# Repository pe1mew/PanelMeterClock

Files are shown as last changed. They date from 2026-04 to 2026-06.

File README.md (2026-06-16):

# PanelMeterClock

A wall clock that displays the current local time on three Siemens 1604P moving-coil panel meters, driven by an ESP32-S3. Hours, minutes, and seconds each have a dedicated meter whose needle deflects proportionally to the time value. Time is obtained via NTP over WiFi, with optional GNSS disciplining for higher accuracy. The device is configured entirely through an embedded web GUI.

## Features

- Three-meter display: hours (0–24), minutes (0–60), seconds (0–60)
- NTP synchronisation over WiFi (`pool.ntp.org` default, configurable)
- Optional GNSS receiver for hardware 1PPS disciplining and precise UTC
- Automatic Daylight Saving Time from GNSS coordinates or IP geolocation
- Embedded web GUI: meter calibration, WiFi config, GNSS config, status, firmware update
- Firmware Over The Air (FOTA) with asymmetric-key signature verification
- mDNS registration (`panelclock.local`) for zero-configuration browser access
- WiFi AP fallback (`PanelClock-XXYY`) when no network credentials are stored
- FreeRTOS firmware on ESP-IDF 5.x / Arduino framework

## Hardware

| Component | Details |
|---|---|
| Microcontroller | WEMOS LOLIN S3 (ESP32-S3-WROOM-1, dual-core 240 MHz, 16 MB flash, 8 MB PSRAM) |
| Panel meters | 3 × Siemens 1604P, 1 V FSD, modified to 3 V FSD by series resistor substitution |
| PWM filter | RC low-pass filter per channel: R = 1 kΩ, C = 4.7 µF, f_c ≈ 34 Hz (PWM 156.25 kHz) |
| Series resistor | 2.0 kΩ ±1 % metal film per meter (measured: I_FSD = 1 mA, R_coil = 82.2 Ω) |
| GNSS receiver | Optional; Quectel L76-M33 (GPS/GLONASS/Galileo/BeiDou, 3.3 V, NMEA 0183, 1PPS, U.FL) |
| GNSS antenna | SMA female chassis connector (J1) via U.FL-to-SMA pigtail; external active or passive antenna |
| Power supply | 5 V via USB-C (LOLIN S3 on-board regulator) |

## Repository Structure

```
PanelMeterClock/
│
├── Design/                              ← Project design documents
│   ├── functionalRequirementsSpecification.md   ← PMC-FRS-001: what the system shall do
│   ├── softwareTechnicalDesign.md               ← PMC-STD-001: firmware architecture
│   ├── hardwareTechnicalDesign.md               ← PMC-HTD-001: circuit design and BOM
│   ├── signatureConciderations.md               ← FOTA signature scheme analysis
│   └── notes.md                                 ← Design trade-off notes
│
├── Documentation/                       ← Component datasheets and reference material
│   ├── esp32-s3-wroom-1_wroom-1u_datasheet_en.pdf
│   ├── esp32-s3_technical_reference_manual_en.pdf
│   ├── dim_s3_v1.0.0.pdf
│   └── sch_s3_v1.0.0.pdf
│
├── Hardware/                            ← Hardware design files
│   └── Scale/                           ← Panel meter scale face designs
│
├── Research/                            ← Standalone PlatformIO validation projects
│   ├── PWMDriver/                       ← PWM driver library (production-ready)
│   │   ├── platformio.ini
│   │   └── src/
│   │       ├── main.cpp
│   │       ├── pwm_driver.h
│   │       └── pwm_driver.cpp
│   ├── PWMTest/                         ← PWM frequency and RC filter verification
│   │   ├── platformio.ini
│   │   └── src/
│   │       └── main.cpp
│   ├── PWMDriver.md                     ← PWM driver design and API documentation
│   └── PWMTest.md                       ← RC filter and frequency verification plan
│
├── README.md
├── LICENSE
├── license.md
├── changelog.md
├── contributing.md
└── code_of_conduct.md
```

## Getting Started

### Prerequisites

- [Visual Studio Code](https://code.visualstudio.com/) with the [PlatformIO IDE extension](https://platformio.org/install/ide?install=vscode)
- Git

### Build and Flash (Research Projects)

The main firmware application is not yet implemented. The `Research/PWMDriver` project validates the PWM driver and RC filter circuit.

1. Clone the repository:
   ```sh
   git clone https://github.com/pe1mew/PanelMeterClock.git
   cd PanelMeterClock
   ```
2. Open `Research/PWMDriver/` in VS Code (PlatformIO detects `platformio.ini` automatically).
3. Connect the LOLIN S3 board via USB-C.
4. Click **Upload** in the PlatformIO toolbar, or run:
   ```sh
   pio run -t upload
   ```
5. Open the **Serial Monitor** at 115200 baud to view PWM and voltage readouts.

### Configuration

The main application is configured through the embedded web GUI at `http://panelclock.local/` once the device is connected to WiFi. On first boot, connect to the fallback AP (`PanelClock-XXYY`) and open `http://192.168.4.1/wifi` to enter WiFi credentials.

## Documentation

| Document | Description |
|---|---|
| [Functional Requirements Specification](Design/functionalRequirementsSpecification.md) | What the system shall do — all functional and non-functional requirements |
| [Software Technical Design](Design/softwareTechnicalDesign.md) | Firmware architecture, FreeRTOS tasks, module design, library choices |
| [Hardware Technical Design](Design/hardwareTechnicalDesign.md) | Circuit design, component values, GPIO assignment, BOM |
| [FOTA Signature Considerations](Design/signatureConciderations.md) | Detached signature scheme analysis and alternatives |
| [PWM Driver Design](Research/PWMDriver.md) | PWM driver API and glitch-free duty update design |
| [PWM Test Plan](Research/PWMTest.md) | RC filter and PWM frequency verification (original 20–80 kHz bench test) |

## License

See [license.md](license.md) for full details.

**Software** (firmware and all code): Source-available, non-commercial. Free to use and modify for personal and non-commercial purposes; redistribution and commercial use are not permitted.

**Hardware design, documentation, and images**: Licensed under the Creative Commons Attribution-NonCommercial-NoDerivatives 4.0 International License.



## Disclaimer

This project is distributed in the hope that it will be useful, but WITHOUT ANY WARRANTY; without even the implied warranty of MERCHANTABILITY or FITNESS FOR A PARTICULAR PURPOSE.

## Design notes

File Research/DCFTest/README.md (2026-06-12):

# DCFTest — DCF77 decoder proof of concept

Proof of concept for the PanelMeterClock DCF77 time source: receive the
demodulated 77.5 kHz time-code signal, decode and validate the one-minute
frame, and report civil CET/CEST time plus derived UTC over the serial
console.

An **ESP-IDF** project (no Arduino layer) with **two interchangeable
decoder components**, both RTOS-aware (dedicated FreeRTOS task, core 0,
priority 7 per PMC-STD-001 §4) with the same callback-driven shape:

* `components/dcf77` — **simple edge-timing decoder**, the PMC-STD-001
  §5.10 baseline. Edge interrupt → pulse-width windows → frame validation →
  consecutive-frame confirmation. Original code, no license constraints.
* `components/dcf77p` — **phase-locked exhaustive decoder**, a C port of
  Udo Klein's blinkenlight decoder (www.blinkenlight.net). 1 kHz sampling →
  100-bin phase convolution → per-second tick classification → 60-bin
  sync-mark scoring → per-field maximum-likelihood (Hamming) binning with
  prediction-driven bin rings. Decodes through noise where individual
  pulses are unreadable. **GPL-3.0** (see below).

`src/main.c` is only the PoC harness: it wires the selected decoder's
callbacks to console printing and stands in for `tick_task`'s epoch
bookkeeping.

```
DCFTest/
├── platformio.ini            framework = espidf, board = lolin_s3
├── CMakeLists.txt            standard IDF project stub
├── sdkconfig.defaults        FREERTOS_HZ=1000, 16 MB flash
├── components/
│   ├── dcf77/                ← edge-timing decoder component
│   │   ├── CMakeLists.txt
│   │   ├── include/dcf77.h
│   │   └── dcf77.c
│   └── dcf77p/               ← phase-locked exhaustive decoder component
│       ├── CMakeLists.txt
│       ├── LICENSE           GPL-3.0 (full text)
│       ├── include/dcf77p.h
│       └── dcf77p.c
└── src/
    ├── CMakeLists.txt        (PRIV_REQUIRES dcf77 dcf77p driver)
    └── main.c                PoC harness: app_main(), printing, LED
```

## Choosing the decoder

`src/main.c`, first line after the header comment:

```c
#define USE_PHASE_DECODER 1   // 1 = dcf77p (Klein port), 0 = dcf77 (edge timing)
```

**License consequence:** `dcf77p` is a derivative of GPL-3.0 code, with the
full text in `components/dcf77p/LICENSE`. Any firmware image that links
`dcf77p` must be distributed under GPL-3.0 terms. The `dcf77` component
carries no such obligation — with `USE_PHASE_DECODER 0` the component is
still compiled but not linked into the image. This was an accepted
trade-off for this research (FDS/TDS deliberately unchanged; the STD still
specifies the simple decoder for the firmware).

Port deviations from the reference sketch
(`Documentation/src/blinkenLightDC77DecoderAll.c`) are documented in
`dcf77p.c`: the year-decoder bit-56 weight bug is fixed, the unused
200-line signal predictor is replaced by its one-line leap-second closed
form, and the AVR busy-wait output is replaced by task-context callbacks.

## Hardware

WEMOS LOLIN S3 dev board + DCF77 receiver module (CME6005-based, see
`Documentation/dcf77.md`). Pinning per PMC-HTD-001 §3/§7:

| Module pin | ESP32-S3 GPIO | Direction | Notes |
|---|---|---|---|
| T (time-code out) | 11 | Input | Internal pull-up enabled (open-collector output, IC-HW-005) |
| P1 (PON / power down) | 12 | Output | **Low = receiver on** (IC-HW-006) |
| V | 3V3 | — | ≈ 1–2 mA |
| G | GND | — | |
| DCF status LED (optional) | 5 | Output | Blinks ~1 Hz while acquiring, steady when valid (PMC-GUI-001) |

Site the ferrite antenna away from the ESP32, USB supply and other switching
noise, broadside toward Frankfurt (PMC-HTD-001 §7.4). Reception is usually
poor right next to a PC/monitor — a metre of separation helps a lot.

## Build and monitor

```
pio run -t upload
pio device monitor
```

115200 baud. Output goes to the default ESP-IDF console = **UART0 / the
CH340 USB port**; the board's native-USB port is unused.

Notes:

* The first build downloads the ESP-IDF framework and toolchain packages
  (large, several minutes); subsequent builds are normal.
* `sdkconfig.defaults` pins `CONFIG_FREERTOS_HZ=1000` (IDF defaults to
  100 Hz) so the decoder's `pdMS_TO_TICKS()`-paced edge flush and watchdog
  keep millisecond granularity. The generated `sdkconfig.esp32s3` is
  git-ignored; delete it to regenerate from the defaults.

## What the serial output looks like

```
DCF77 decoder proof of concept — PanelMeterClock Research/DCFTest
...
[bit ]  ? = 1  (197 ms)  waiting for minute mark
[dcf ] minute mark (1986 ms gap)
[bit ]  0 = 0  (103 ms)  M  start of minute (always 0)
[bit ]  1 = 0  (104 ms)  civil warning / weather
...
[bit ] 58 = 1  (195 ms)  P3 date parity
[dcf ] minute mark (1992 ms gap)
[frame] 0 00111010011010 0 0 1 0 0 1 10101100 0010100 010010 101 01100 011001001
[frame] OK: Fri 2026-06-12 14:35:00 CEST = 12:35 UTC
[frame] awaiting confirmation by the next frame (FR-DCF-007)
... (one more minute of bits) ...
[dcf ] minute mark (1989 ms gap)
[frame] 0 01001011010010 0 0 1 0 0 1 01101100 0010100 010010 101 01100 011001001
[frame] OK: Fri 2026-06-12 14:36:00 CEST = 12:36 UTC
==========================================================
[time] CONFIRMED by two consecutive frames (FR-DCF-007)
==========================================================
[time] 2026-06-12 14:36:00 CEST (UTC 12:36:00)
[time] 2026-06-12 14:36:01 CEST (UTC 12:36:01)
...
[stat] LOCKED | second 23 | edges 412 (3 glitches) | bits 142 ok / 1 bad | frames 2 ok / 0 bad | confirmed 1
```

A first confirmed time takes 2–5 minutes with decent reception: partial
first minute → one full frame → confirmation by the next frame.

With the phase-locked decoder (`USE_PHASE_DECODER 1`) the output instead
shows the acquisition stages and per-minute tick classifications:

```
Decoder: dcf77p — phase-locked exhaustive (Udo Klein port, GPL-3.0)
...
==== state: OFF -> ACQUIRING_PHASE ====
[stat] ACQUIRING_PHASE | sec 0 | ticks S:0 ?:0 0:0 1:0 | phase 64-58 | ...
==== state: ACQUIRING_PHASE -> ACQUIRING_SECOND ====
[tick] 0100110100101S01101011000010100010010101011000110010010S010  (no second lock)
==== state: ACQUIRING_SECOND -> DECODING ====
[dec ] --:--:23  date 20----    (fields locking)
[dec ] --:36:24  date 2026-06-12  (fields locking)
[min ] 00011101001101000101101011000010100010010101011000110010010
==== state: DECODING -> TIME_VALID ====
[time] full date/time determined by exhaustive decoding
[time] 2026-06-12 Fri 14:36:31 CEST (UTC 12:36:31)
[time] 2026-06-12 Fri 14:36:32 CEST (UTC 12:36:32)
```

With good signal the phase lock arrives within ~1 minute and the full time
typically within 3–6 minutes; with poor signal the exhaustive decoder keeps
integrating and can take tens of minutes — but it converges at noise levels
where the edge-timing decoder never produces a clean frame at all.

## How it works — dcf77 (edge timing)

```
GPIO 11 CHANGE ISR ──(timestamped edges)──▶ FreeRTOS queue ──▶ dcf77 task
                                                              (core 0, prio 7,
                                                               PMC-STD-001 §4)
```

* **Glitch filter** — two edges closer together than 20 ms annihilate, so RF
  spikes never reach the decoder. Acceptance of a real edge is delayed by at
  most ~45 ms; events carry the original edge timestamp.
* **Bit classification** — mark width 40–130 ms → `0`, 140–260 ms → `1`,
  anything else poisons the frame and is reported (`PULSE_REJECT`).
* **Second/minute sync** — leading-edge-to-leading-edge period 800–1200 ms →
  next second; 1700–2300 ms → missing 59th mark = minute boundary. Other
  periods drop bit alignment (`RESYNC`).
* **Frame validation (FR-DCF-006)** — 59 bits, bit 0 = 0, bit 20 = 1,
  Z1 ≠ Z2, even parity P1/P2/P3, BCD digit validity, field ranges,
  day-in-month, and weekday cross-checked against the date.
* **Confirmation (FR-DCF-007)** — a decoded time is only reported as
  `TIME_CONFIRMED` once two consecutive frames are exactly one minute apart.
* **UTC (FR-DCF-009)** — broadcast time is civil CET/CEST; the module derives
  the UTC epoch using the Z1/Z2 zone bits (CET = UTC+1, CEST = UTC+2).
* **Ticks (FR-DCF-012)** — every accepted mark leading edge fires a tick
  callback; in the firmware this feeds `tick_task` as the Priority-2 tick
  source.

## How it works — dcf77p (phase-locked exhaustive)

```
1 kHz esp_timer cb ──(10 ms majority bits)──▶ FreeRTOS queue ──▶ dcf77p task
(sampling only)                                                 (core 0, prio 7)
```

* **Phase lock** — each 10 ms slot feeds a saturating up/down counter in
  one of 100 phase bins (cap 300 ≈ 5 min of integration). A sliding
  convolution with the expected pulse shape (2× weight first 100 ms, 1×
  second 100 ms) finds the second boundary; the same kernel 200 ms out of
  phase estimates the noise floor. No edges are ever measured.
* **Tick classification** — the 220 ms window after each boundary is split
  into two 110 ms halves; their majorities yield sync-mark / 0 / 1 /
  undefined per second.
* **Second lock** — a 60-bin scoring scheme (+6 for a sync mark, ±1/−2
  cross-evidence from 0/1 bits, exploiting "bit 0 = 0, bit 20 = 1") finds
  which second of the minute we are in.
* **Exhaustive field decoding** — every minute, each calendar field scores
  *all* its candidate values (60 minutes, 24 hours, 31 days, …) by Hamming
  distance against the received bits (parity included for minute/hour);
  evidence accumulates per candidate in rings that the predicted time keeps
  rotating in lock-step (timezone jumps and month lengths handled by the
  prediction). The best candidate wins once it leads the runner-up by ≥ 2 —
  effectively a maximum-likelihood decoder integrating over minutes.
* **Output** — at every predicted second boundary the controller advances
  the reconstructed time and publishes it (`DCF77P_EVT_SECOND` + tick
  callback, FR-DCF-012); `valid` is set once all fields are determined and
  mutually plausible, and the UTC epoch is derived from the zone bits
  (FR-DCF-009). Trust is structural here: a field value only emerges after
  consistent evidence across minutes, which subsumes the two-frame
  confirmation idea of FR-DCF-007.

## Polarity (FR-DCF-004)

The decoder expects the carrier-reduction mark as a **HIGH** pulse by
default. If your module idles high and pulls low during the mark, the PoC
will print rejected marks of ~800/900 ms and a hint; set

```c
cfg.signal_inverted = true;
```

in `app_main()`.

## Reusing the component in the firmware

* Copy `components/dcf77/` into the firmware's `components/` directory and
  add `dcf77` to the consumer's `PRIV_REQUIRES` — done. The component
  depends only on `driver` (GPIO), `esp_timer` and FreeRTOS; the header is
  C++-safe (`extern "C"` guards). Multiple instances are supported (the ISR
  receives the instance pointer).
* The component installs the shared GPIO ISR service with flags 0 and
  tolerates `ESP_ERR_INVALID_STATE` if the firmware installed it already
  (the GNSS 1PPS and encoder inputs will share it). If the firmware installs
  the service with `ESP_INTR_FLAG_IRAM`, replace the `gpio_get_level()` call
  in the ISR with a register read (see note in `dcf77.c`).
* Callbacks run in the decoder task context — keep them short; hand data to
  other tasks via the usual primitives (the firmware will set the shared
  epoch and notify `tick_task` instead of printing).
* `dcf77_stop()` disables the pin interrupt, removes the handler and holds
  PON off, matching the "disabled consumes no resources" requirement
  (FR-DCF-002); the firmware's NVS flag `dcf77_enabled` maps to start/stop.
* Constants meant for `config.h` (PMC-STD-001 §7): `DCF77_SIGNAL_GPIO` 11,
  `DCF77_PON_GPIO` 12, plus the timing windows in `dcf77_config_default()`.

## Known limitations (PoC scope)

* No free-running bridge across reception gaps — the printed clock simply
  stops when marks stop; in the firmware that is `tick_task`'s job
  (FR-TIM-007). Re-confirmation resumes it.
* `signal_lost_ms` is 5 s for fast bench feedback; the firmware uses
  `DCF77_SIGNAL_LOST_TIMEOUT_S` = 300 (FR-DCF-010).
* A leap-second minute (60 marks) is rejected as a 60-bit frame — one bad
  minute, then normal recovery.
* The simple edge-timing decoder needs a reasonably clean signal; for
  marginal sites the phase-locked `dcf77p` component is the implemented
  alternative (`USE_PHASE_DECODER 1`, GPL-3.0).
* `dcf77p` ports the decoder stages of Klein's sketch but not the later
  library's local-clock flywheel or crystal frequency tuning — during deep
  fades the published seconds keep ticking from the phase prediction, but
  long outages degrade the locks rather than free-running on a disciplined
  local oscillator.
* `dcf77p` samples via a 1 kHz `esp_timer` callback (task-dispatched). That
  is jitter-tolerant by design (10 ms bins, minutes of integration), but a
  heavily loaded system could still starve it; the firmware-grade upgrade
  is a GPTimer ISR feeding the same queue.

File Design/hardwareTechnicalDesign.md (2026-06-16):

# Hardware Technical Design
## PanelMeterClock

---

## 1. Document Control

### 1.1 Identification

| Field | Value |
|---|---|
| Document title | Hardware Technical Design — PanelMeterClock |
| Document ID | PMC-HTD-001 |
| Version | 0.2 (draft) |
| Date | 2026-06-15 |
| Author | Remko Welling |
| Status | Draft — under review |

### 1.2 Revision History

| Version | Date | Author | Change Summary |
|---|---|---|---|
| 0.1 | 2026-04-29 | Remko Welling | Initial draft; hardware design content migrated from PMC-FRS-001 and supplemented with circuit analysis |
| 0.2 | 2026-06-15 | Remko Welling | Raised meter PWM to 156.25 kHz and reduced the RC filter capacitor to 4.7 µF (f_c ≈ 33.9 Hz, −73 dB at PWM) to clear the 77.5 kHz DCF77 band; updated §4.2/§4.4/§5/§11; added EMC open issue HW-011 and hardware test HV-11; corrected the §12 table header |

### 1.3 Relationship to Other Documents

| Document | Role |
|---|---|
| PMC-FRS-001 Functional Requirements Specification | Defines *what* the system shall do |
| PMC-STD-001 Software Technical Design | Defines firmware architecture and module design |
| PMC-GUI-001 GUI / User Interface Specification | Defines the physical operator interface (panel, status LEDs, encoder, connectors) |
| This document (PMC-HTD-001) | Defines *how* the hardware is designed and wired |

---

## 2. Target Hardware Platform

### 2.1 Microcontroller Module — ESP32-S3-WROOM-1-N16R8

| Attribute | Value |
|---|---|
| Module | Espressif ESP32-S3-WROOM-1-N16R8 |
| CPU | Xtensa LX7 dual-core, up to 240 MHz |
| Flash | 16 MB quad SPI (N16) |
| PSRAM | 8 MB octal SPI (R8) |
| SRAM | 512 KB |
| WiFi | 802.11b/g/n 2.4 GHz |
| GPIO voltage | 3.3 V (not 5 V-tolerant) |
| USB | Module native USB (USB-CDC / USB-Serial-JTAG) on GPIO 19/20; the project PCB provides USB-C and the debug UART (HW-010) |
| Operating supply | 3.3 V or 5 V via USB |

### 2.2 Available GPIO on the ESP32-S3-WROOM-1

The table below lists all GPIO pins available for application use after reserving the fixed-function pins.

| GPIO | Reserved for | Direction | Notes |
|---|---|---|---|
| 0 | Strapping / Boot | — | Do not use; affects boot mode |
| 3 | Strapping | — | Do not use |
| 19 | USB D− (UART0 / USB-CDC) | — | Debug serial |
| 20 | USB D+ (UART0 / USB-CDC) | — | Debug serial |
| 26–32 | In-package SPI flash (N16) | — | Not accessible |
| 33–37 | In-package octal SPI PSRAM (R8) | — | Not accessible on N16R8 |
| 43 | UART0 TX (CH340) | Output | Debug serial TX |
| 44 | UART0 RX (CH340) | Input | Debug serial RX |
| 45 | Strapping | — | Avoid |
| 46 | Strapping / input-only | Input only | No internal pull |
| All others | Application use | I/O | 3.3 V max |

---

## 3. GPIO Pin Assignment

All application GPIO assignments are listed below. This table is the single authoritative source for pin allocation; firmware constants in `config.h` (PMC-STD-001 §7) shall match these values.

| GPIO | Signal | Direction | Peripheral | Connected to | Requirement |
|---|---|---|---|---|---|
| 4 | LED — RTC status | Output | GPIO | Front-panel status LED (series R) | IC-HW-008, PMC-GUI-001 |
| 5 | LED — DCF status | Output | GPIO | Front-panel status LED (series R) | IC-HW-008, PMC-GUI-001 |
| 6 | LED — NTP status | Output | GPIO | Front-panel status LED (series R) | IC-HW-008, PMC-GUI-001 |
| 7 | LED — GNSS status | Output | GPIO | Front-panel status LED (series R) | IC-HW-008, PMC-GUI-001 |
| 8 | I2C SDA | I/O | I2C | DS1307 RTC (via 3.3 V↔5 V level shifter) | IC-HW-007 |
| 9 | I2C SCL | Output | I2C | DS1307 RTC (via 3.3 V↔5 V level shifter) | IC-HW-007 |
| 10 | GNSS 1PPS | Input | GPIO interrupt | GNSS module 1PPS output | IC-HW-003 |
| 11 | DCF77 time-code | Input | GPIO interrupt | DCF77 receiver time-code output | IC-HW-005 |
| 12 | DCF77 enable (PON) | Output | GPIO | DCF77 receiver enable input | IC-HW-006 |
| 13 | Encoder A | Input | GPIO interrupt | Rotary encoder channel A (pull-up) | IC-HW-009, PMC-GUI-001 |
| 14 | Encoder B | Input | GPIO interrupt | Rotary encoder channel B (pull-up) | IC-HW-009, PMC-GUI-001 |
| 15 | PWM Hours | Output | LEDC_CHANNEL_0 / LEDC_TIMER_0 | RC filter → Hours meter | IC-HW-001 |
| 16 | PWM Minutes | Output | LEDC_CHANNEL_1 / LEDC_TIMER_1 | RC filter → Minutes meter | IC-HW-001 |
| 17 | PWM Seconds | Output | LEDC_CHANNEL_2 / LEDC_TIMER_2 | RC filter → Seconds meter | IC-HW-001 |
| 18 | GNSS UART RX | Input | UART1 | GNSS module TX | IC-HW-004 |
| 19 | USB D− | — | USB-CDC / UART0 | USB connector | Fixed |
| 20 | USB D+ | — | USB-CDC / UART0 | USB connector | Fixed |
| 21 | GNSS UART TX | Output | UART1 | GNSS module RX | IC-HW-004 |
| 43 | Debug TX | Output | UART0 / CH340 | USB-serial chip | Fixed |
| 44 | Debug RX | Input | UART0 / CH340 | USB-serial chip | Fixed |
| 47 | Encoder button | Input | GPIO interrupt | Encoder push button (pull-up) | IC-HW-009, PMC-GUI-001 |

GPIO 10 is configured as input-only with no internal pull resistor (IC-HW-003). GPIO 11 (DCF77 time-code) is an interrupt-capable input with the internal pull-up enabled (IC-HW-005); GPIO 12 (DCF77 enable) is a push-pull output (IC-HW-006). GPIO 8/9 carry the I2C bus to the DS1307 RTC via a 3.3 V↔5 V level shifter (IC-HW-007). GPIO 4–7 drive the four front-panel status LEDs (push-pull, each with a series resistor); GPIO 13/14 are the rotary-encoder A/B channels and GPIO 47 the encoder push button — all inputs with internal pull-ups and firmware debounce (PMC-GUI-001). All PWM outputs are push-pull 3.3 V. GPIO 21 (GNSS TX) may be left unconnected if the GNSS module requires no runtime configuration.

---

## 4. Panel Meter Drive Circuit

### 4.1 Panel Meter — Siemens 1604P

| Parameter | Value |
|---|---|
| Type | Moving-coil (D'Arsonval) DC panel meter |
| Full-scale deflection (FSD) voltage | 1 V (across meter terminals, factory) |
| Original series resistor | Present in factory configuration; limits current to rated FSD |
| Modified full-scale voltage | 3 V (after series resistor substitution — see §4.3) |
| Scale range | 0 – FSD (linear, continuous) |

### 4.2 Circuit Overview

Each of the three meter channels follows the same topology:

```
ESP32-S3 GPIO ──┬── R_filter (1 kΩ) ──┬── R_series ──[ Meter coil ]── GND
                │                     │
               (PWM)               C_filter
                                   (4.7 µF)
                                      │
                                     GND
```

The RC low-pass filter converts the PWM waveform to a quasi-DC voltage. The series resistor limits the current through the meter coil so that the maximum filter output voltage (3 V) causes exactly full-scale deflection.

### 4.3 Series Resistor Modification

The factory series resistor is sized for a 1 V drive source. It must be replaced with a higher value to adapt the meter to the 3 V PWM output.

**Measured values (Siemens 1604P, this build):**

| Parameter | Symbol | Measured value |
|---|---|---|
| Full-scale current | I_FSD | 1.000 mA |
| Full-scale voltage (coil terminals) | V_FSD | 82.2 mV |
| Coil resistance (derived) | R_coil | 82.2 Ω |

**Formula:**

The DC current path is GPIO → R_filter → R_series → coil → GND. R_filter (1 kΩ) is in series at DC and must be included:

```
R_series = V_drive / I_FSD − R_filter − R_coil
```

**Calculation:**

```
R_series = 3.00 V / 1.000 mA − 1 000 Ω − 82.2 Ω
         = 3 000 − 1 000 − 82.2
         = 1 917.8 Ω
```

Nearest E24 standard value: **2.0 kΩ** (next value up, safe — avoids over-deflection).  
With 2.0 kΩ fitted: I = 3.00 V / (1 000 + 2 000 + 82.2) Ω = **0.973 mA = 97.3 % FSD**.  
The 2.7 % shortfall is trimmed by the per-meter `full_scale` NVS calibration value (FR-DSP-011).

**Note:** R_coil varies between individual meters even of the same type. Measure each meter and calculate its series resistor individually. Use a close-tolerance resistor (±1 % metal film) to ensure calibration accuracy is not limited by component tolerance.

**Design point:** The firmware uses a full-scale duty of 232/255, corresponding to:

```
V_out_max = (232 / 255) × 3.3 V = 3.00 V
```

The 3.3 V GPIO maximum is deliberately not used as the full-scale point. This provides a ≈ 0.3 V safety margin and ensures the meter never reaches mechanical end-stop from a firmware glitch. Firmware constants: `PWM_FULL_SCALE_DUTY = 232`, `V_DRIVE_FULL_SCALE = 3.0 V`.

### 4.4 RC Low-Pass Filter Design

One RC filter is fitted per channel. Values and rationale:

| Component | Value | Tolerance | Notes |
|---|---|---|---|
| R_filter | 1 kΩ | ±5 % (±1 % preferred) | Carbon or metal film; rated ≥ 100 mW |
| C_filter | 4.7 µF | ±20 % | Electrolytic, positive terminal toward GPIO (or non-polar film/ceramic) |

**Cutoff frequency:**

```
f_c = 1 / (2π × R × C) = 1 / (2π × 1 000 × 4.7 × 10⁻⁶) ≈ 33.9 Hz
```

**Attenuation at PWM frequency (156.25 kHz):**

```
A = 20 × log₁₀(f_c / f_PWM) = 20 × log₁₀(33.9 / 156 250) = −73 dB
```

At −73 dB the PWM ripple reaching the meter is negligible (< 0.3 mV peak). Residual mechanical damping of the moving-coil meter suppresses any remaining ripple further.

**DC gain:** 0 dB (unity). The filter introduces no attenuation at DC; the output voltage at any steady duty cycle equals `(duty / 255) × 3.3 V` within the accuracy of the resistor and capacitor tolerances.

**Settling time:** The RC time constant τ = R × C = 4.7 ms. Full settling to < 1 % error requires ≈ 5τ = 24 ms. The panel meter's mechanical inertia (settling time > 500 ms) dominates entirely, so the RC settling time is not the limiting factor.

### 4.5 PWM-to-Voltage-to-Deflection Mapping

| Duty (decimal) | V_out | Meter deflection |
|---|---|---|
| 0 | 0.00 V | 0 % (zero) |
| 64 | 0.83 V | 25 % |
| 128 | 1.66 V | 50 % |
| 192 | 2.49 V | 75 % |
| 232 | 3.00 V | 100 % (FSD) |
| 255 | 3.30 V | > FSD — **do not use** |

The firmware clamps duty to [0, 232] at the display layer. Firmware factory defaults: `zero_offset = 0`, `full_scale = 232` (FR-DSP-014).

---

## 5. LEDC PWM Configuration

The ESP32-S3 LEDC peripheral generates all three PWM signals independently.

| Parameter | Value | Notes |
|---|---|---|
| Clock source | APB clock (80 MHz) | Stable; not affected by CPU frequency scaling |
| PWM frequency | 156 250 Hz | Ultrasonic; clears the 77.5 kHz DCF77 band (§7.4, HW-011); above panel meter mechanical response |
| Resolution | 8 bits (256 steps) | Gives 256 duty positions; adequate for meter accuracy |
| Full-scale duty register value | 232 | Corresponds to 3.00 V output |

**Channel and timer assignment:**

| Meter | GPIO | LEDC channel | LEDC timer |
|---|---|---|---|
| Hours | 15 | LEDC_CHANNEL_0 | LEDC_TIMER_0 |
| Minutes | 16 | LEDC_CHANNEL_1 | LEDC_TIMER_1 |
| Seconds | 17 | LEDC_CHANNEL_2 | LEDC_TIMER_2 |

Each meter uses a dedicated timer so that the PWM frequency of one channel can be changed independently without affecting the others (used during development/calibration).

**Frequency validation:** The original RC + PWM bench test (`Research/PWMTest`) validated the filtering approach across 20–80 kHz with a 10 µF capacitor. The operating point was subsequently **raised to 156.25 kHz** to clear the 77.5 kHz DCF77 reception band — the former 80 kHz fundamental sat only 2.5 kHz away (see §7.4 and HW-011) — and the filter capacitor reduced to 4.7 µF to suit (§4.4). Selection criteria: ultrasonic (> 20 kHz); the fundamental and all harmonics clear of 77.5 kHz (harmonics lie above the fundamental, so a fundamental ≥ 100 kHz cannot fall on 77.5 kHz); the filter corner > 70 dB below the PWM frequency; and an exact integer divider from the 80 MHz LEDC clock (80 MHz ÷ 512 = 156.25 kHz — i.e. ÷2 with 8-bit duty resolution; the 8-bit maximum is 312.5 kHz).

---

## 6. GNSS Hardware Interface

### 6.0 Module — Quectel L76-M33

| Parameter | Value |
|---|---|
| Part number | Quectel L76-M33 |
| Constellations | GPS (L1 C/A), GLONASS (L1OF), Galileo (E1B/C), BeiDou (B1I), QZSS (L1 C/A) |
| Supply voltage (VCC) | 3.3 V (2.8 V – 3.6 V) |
| Backup voltage (VBAT) | 3.0 V nominal (maintains RTC and almanac across power cycles) |
| UART default baud rate | 9 600 baud, 8-N-1 |
| UART configurable baud rates | 4 800 / 9 600 / 14 400 / 19 200 / 38 400 / 57 600 / 115 200 via PMTK command |
| NMEA sentences | $GPRMC, $GPGGA, $GPGSV, $GPGSA, $GNRMC, $GNGGA (and others) |
| 1PPS output voltage | 3.3 V logic (active HIGH, configurable pulse width, default 100 ms) |
| Antenna connector | U.FL (IPEX) on-module |
| Acquisition current | ≈ 18 mA (typical) |
| Tracking current | ≈ 15 mA (typical) |
| Standby current | ≈ 1 mA |
| Cold-start TTFF | ≈ 30 s (open sky, no almanac) |
| Hot-start TTFF | ≈ 1 s (valid almanac and ephemeris in VBAT-retained RAM) |
| Tracking sensitivity | −165 dBm |
| Package | LCC, 10.1 × 9.7 × 2.5 mm |
| Reference document | `Documentation/` — Quectel L76-M33 Hardware Design Guide and Product Specification |

### 6.1 Signal Overview

| Signal | L76-M33 pin | ESP32-S3 GPIO | Level | Notes |
|---|---|---|---|---|
| UART RX (ESP ← GNSS) | TXD | 18 | 3.3 V | NMEA sentence output |
| UART TX (ESP → GNSS) | RXD | 21 | 3.3 V | PMTK command input |
| 1PPS (ESP ← GNSS) | 1PPS | 10 | 3.3 V | Rising-edge interrupt; 100 ms pulse (default) |
| Module power | VCC | — | 3.3 V | Supplied from 3.3 V rail |
| Backup power | VBAT | — | 3.0 V | Coin cell or supercapacitor (see §6.6) |

### 6.2 Level Shifting

The L76-M33 operates natively at 3.3 V. All UART and 1PPS signals are directly compatible with ESP32-S3 GPIO logic levels. **No level shifter is required.**

### 6.3 UART Configuration

| Parameter | Value | Configurable |
|---|---|---|
| Peripheral | UART1 | No |
| RX GPIO | 18 | No |
| TX GPIO | 21 | No |
| Baud rate | 9 600 (default) | Yes — NVS key `clock/gnss_baud`; change applied via PMTK set-baud command then firmware reconnect |
| Frame format | 8-N-1 | No |

At 9 600 baud a complete `$GPRMC` sentence (≈ 70 bytes) arrives in ≈ 73 ms, well within the 1-second tick budget. To change the baud rate at runtime the firmware sends `$PMTK251,<baud>*<checksum><CR><LF>` before reopening UART1 at the new rate.

### 6.4 1PPS Signal

The L76-M33 1PPS output is 3.3 V active-HIGH with a default pulse width of 100 ms. GPIO 10 is configured as a rising-edge interrupt with no internal pull resistor. The ISR has a latency budget of < 10 µs (hardware interrupt response on LX7 core). The interrupt is enabled only while `gnss_task` is running (GNSS enabled).

### 6.5 Antenna

The L76-M33 has an on-module **U.FL (IPEX)** antenna connector. A short U.FL-to-SMA pigtail cable (W1, ≈ 100 mm) connects the module to the **SMA female chassis-mount connector (J1)** on the enclosure panel. An external active or passive GNSS antenna with SMA male plug connects to J1.

Active antennas (with built-in LNA) are recommended for enclosures with limited sky view. The L76-M33 supports active antennas directly; no external LNA bias circuit is required.

### 6.6 Backup Power (VBAT)

The VBAT pin maintains the L76-M33 internal RTC and almanac/ephemeris RAM across main-power cycles, enabling hot-start acquisition (≈ 1 s TTFF vs. ≈ 30 s cold start).

| Option | Component | Notes |
|---|---|---|
| Coin cell (recommended) | MS621FE rechargeable LiMnO₂, 3.0 V | Self-contained; no charge circuit needed; ≈ 2–3 year lifetime at VBAT quiescent current |
| Supercapacitor | 0.1 F, 3.3 V | Maintains data for several hours after power-off; no battery management |
| No backup | — | Cold start only (≈ 30 s TTFF); simpler circuit |

Connect VBAT through a Schottky diode (e.g. BAT54, V_f ≈ 0.3 V) from the 3.3 V rail if the coin cell or supercapacitor is omitted, to prevent VBAT floating.

---

## 7. DCF77 Receiver Interface

### 7.0 Module — DCF77 Longwave Receiver

| Parameter | Value |
|---|---|
| Signal | DCF77 longwave time signal, 77.5 kHz |
| Transmitter | Mainflingen, Germany (PTB atomic-clock reference) |
| Coverage | ≈ 2 000 km radius (Central Europe) |
| Antenna | Ferrite rod (supplied with module) |
| Supply voltage | 3.3 V |
| Output | Demodulated time-code; one mark per second (open-collector, requires pull-up) |
| Enable input | Power-on (PON) control line |
| Typical current | ≈ 1–2 mA |

### 7.1 Signal Overview

| Signal | Module pin | ESP32-S3 GPIO | Level | Notes |
|---|---|---|---|---|
| Time-code output | TCO / OUT | 11 | 3.3 V | One mark/second; ≈ 100 ms = 0, ≈ 200 ms = 1; gap at second 59 |
| Enable | PON / EN | 12 | 3.3 V | Powers the receiver on/off |
| Power | VCC | — | 3.3 V | From 3.3 V rail |
| Ground | GND | — | 0 V | Common ground |

### 7.2 Level Shifting

The receiver operates at 3.3 V; its output is directly compatible with ESP32-S3 GPIO logic levels. **No level shifter is required.** The open-collector time-code output uses the ESP32-S3 internal pull-up on GPIO 11 (IC-HW-005).

### 7.3 Time-Code Signal

DCF77 transmits one amplitude-reduced mark per second: ≈ 100 ms for a binary 0 and ≈ 200 ms for a binary 1, with no mark in the 59th second to delimit the minute. GPIO 11 is configured as an edge interrupt; the firmware measures each pulse width to decode the bits and assembles the one-minute frame (PMC-STD-001 §5.10). The leading edge of each mark is an on-time second boundary and is also used as a 1-second tick reference (FR-DCF-012). Signal polarity is configurable in firmware (FR-DCF-004) to accommodate modules with inverted outputs.

### 7.4 Antenna and Siting

The ferrite-rod antenna should be mounted away from switching-noise sources (the ESP32-S3, the USB supply and the panel-meter PWM lines) and oriented broadside toward Frankfurt for best reception. Reception is region-specific (DC-007) and is generally weaker indoors than GNSS; DCF77 is therefore an optional, supplementary time source.

---

## 8. RTC Interface

### 8.0 Device — DS1307Z

| Parameter | Value |
|---|---|
| Part | Maxim DS1307Z (SOIC-8) |
| Type | I2C real-time clock + 56-byte NVRAM |
| I2C address | 0x68 (fixed) |
| Supply voltage | 5 V (4.5 – 5.5 V) |
| Backup | VBAT coin cell, 3 V (CR2032) |
| Timebase | external 32.768 kHz crystal (12.5 pF) |
| Typical current | ≈ 1.5 mA (VCC) / ≈ 300–500 nA (battery, powered off) |
| SQW/OUT | not used in this design |

### 8.1 Signal Overview

| Signal | DS1307 pin | ESP32-S3 GPIO | Level | Notes |
|---|---|---|---|---|
| I2C SDA | SDA | 8 | 3.3 V ↔ 5 V (shifted) | Via level shifter |
| I2C SCL | SCL | 9 | 3.3 V ↔ 5 V (shifted) | Via level shifter |
| Supply | VCC | — | 5 V | From the USB 5 V rail |
| Backup | VBAT | — | 3 V | CR2032 coin cell |
| Crystal | X1 / X2 | — | — | 32.768 kHz, 12.5 pF |

### 8.2 5 V Operation and Level Shifting

The DS1307 requires a 5 V supply, and its logic-high threshold (V_IH ≈ 0.7 × VCC ≈ 3.5 V) is above the ESP32-S3's 3.3 V output. The I2C bus is therefore routed through a **bidirectional MOSFET level shifter** (3.3 V on the ESP32 side, 5 V on the DS1307 side) with pull-ups on each side. The ESP32-S3 is not 5 V tolerant, so the DS1307 I2C lines must not connect to it directly.

*(A 3.3 V RTC such as the DS3231 would remove the level shifter and improve accuracy; the DS1307Z is the selected part — see PMC-STD-001 §5.11.)*

### 8.3 Backup Battery

A CR2032 coin cell on VBAT keeps the DS1307 running while main power is off, so the time of day is retained (FR-RTC-001). The DS1307 clock-halt / oscillator-stopped flag is read at boot to detect a depleted cell or first use (FR-RTC-005).

---

## 9. Serial Debug Interface

| Parameter | Value |
|---|---|
| Interface | UART0, also exposed via CH340 USB-serial chip |
| USB connector | USB-C on the project PCB |
| Baud rate | 115 200 baud, 8-N-1 |
| GPIO (UART0 TX) | 43 |
| GPIO (UART0 RX) | 44 |
| ESP-IDF console | `esp_log` / `ESP_LOGx` on UART0 |

Firmware logging uses the ESP-IDF console (`esp_log`) on UART0, exposed through the on-board USB-UART (HW-010). Alternatively the module's native USB-Serial-JTAG can carry the console over USB-C, which removes the need for a separate USB-UART chip.

---

## 10. Power Supply

| Parameter | Value | Notes |
|---|---|---|
| Input supply | 5 V via USB-C | Stepped down by the on-board 3.3 V regulator |
| 3.3 V rail | On-board LDO regulator | Supplies ESP32-S3 and GPIO outputs |
| GPIO output current per pin | 40 mA maximum | ESP32-S3 absolute maximum |
| Total GPIO current budget | 1 200 mA maximum (sum of all outputs) | Practical limit lower due to LDO rating |
| Panel meter coil current per channel | ≤ I_FSD (≈ 1 mA typical) | Negligible relative to GPIO budget |
| RC filter current per channel | V_out / R_filter ≈ 3 V / 1 kΩ = 3 mA max | Dominates over meter coil current |
| Total current from GPIO pins (3 channels) | ≤ 10 mA | Well within limits |
| GNSS module (L76-M33), acquisition | ≈ 18 mA | Supplied from 3.3 V rail |
| GNSS module (L76-M33), tracking | ≈ 15 mA | Typical steady-state |
| DCF77 receiver module | ≈ 1–2 mA | Supplied from 3.3 V rail; negligible |
| DS1307 RTC | ≈ 1.5 mA | Supplied from the 5 V rail; ≈ µA on the backup battery when powered off |
| Total estimated system current | ≤ 300 mA | ESP32-S3 WiFi active (≈ 240 mA peak) dominates |

The L76-M33 adds ≤ 18 mA to the 3.3 V rail. The on-board 3.3 V LDO regulator shall be rated for at least 500 mA output; total system current remains well within that limit.

---

## 11. Component List (Partial)

This list covers the signal conditioning and display subsystem. Connectors, PCB, and enclosure are out of scope.

| Qty | Reference | Description | Value / Part number |
|-----|---|---|---|
| 1 | U1 | Microcontroller module | Espressif ESP32-S3-WROOM-1-N16R8 (16 MB flash + 8 MB octal PSRAM) |
| 1 | U6 | 3.3 V regulator | LDO, 5 V → 3.3 V, ≥ 500 mA (project PCB; see HW-010) |
| 1 | J2 | USB-C connector | USB 2.0 — power + native USB data (project PCB; see HW-010) |
| 1 | U7 | USB-UART bridge (optional) | CH340 on UART0 for debug, or use the module's native USB-Serial-JTAG (HW-010) |
| 3 | M1–M3 | Panel meter | Siemens 1604P, 1 V FSD, DC |
| 3 | R1–R3 | RC filter resistor | 1 kΩ ±1 %, metal film, 250 mW |
| 3 | C1–C3 | RC filter capacitor | 4.7 µF, 16 V (electrolytic radial, or non-polar film/ceramic) |
| 3 | R4–R6 | Panel meter series resistor | 2.0 kΩ ±1 %, metal film (per §4.3; measured I_FSD = 1 mA, R_coil = 82.2 Ω) |
| 1 | U2 | GNSS receiver module | Quectel L76-M33 (multi-constellation, 3.3 V, NMEA 0183, 1PPS, U.FL) |
| 1 | BT1 | GNSS backup battery | MS621FE rechargeable 3.0 V LiMnO₂ coin cell (or 0.1 F supercapacitor) |
| 1 | W1 | GNSS antenna pigtail | U.FL male to SMA male, ≈ 100 mm |
| 1 | J1 | GNSS antenna connector | SMA female, chassis mount |
| 1 | U3 | DCF77 receiver module | 77.5 kHz longwave receiver with ferrite antenna, 3.3 V, demodulated time-code output |
| 1 | E1 | DCF77 ferrite antenna | Ferrite-rod antenna (supplied with U3) |
| 1 | U4 | Real-time clock | Maxim DS1307Z (I2C, SOIC-8) |
| 1 | Y1 | RTC crystal | 32.768 kHz, 12.5 pF load |
| 1 | BT2 | RTC backup battery | CR2032 coin cell + holder, 3 V |
| 1 | U5 | I2C level shifter | Bidirectional 3.3 V ↔ 5 V, 2-channel (e.g. BSS138-based) |
| 2 | R7,R8 | I2C pull-up resistors | 4.7 kΩ (3.3 V side; 5 V side per shifter module) |
| 4 | D1–D4 | Status LEDs | White, 3 mm — front panel RTC/DCF/NTP/GNSS |
| 4 | R9–R12 | LED series resistors | ≈ 1 kΩ (tune for brightness) |
| 1 | SW1 | Rotary encoder | Incremental quadrature encoder with push button |

---

## 12. Open Hardware Issues

| ID | Item | Status |
|----|---|---|
| HW-001 | GNSS module selection | ✅ Resolved — Quectel L76-M33; 3.3 V, no level shifter required, U.FL antenna connector, default 9 600 baud (see §6) |
| HW-002 | Series resistor values R4–R6 | ✅ Resolved — I_FSD = 1 mA, V_FSD = 82.2 mV, R_coil = 82.2 Ω → R_series = 2.0 kΩ E24 (see §4.3) |
| HW-004 | GNSS antenna connector | ✅ Resolved — SMA female chassis connector |
| HW-005 | DCF77 receiver module selection | ⚠ Open — generic 77.5 kHz module assumed (3.3 V, demodulated time-code output); confirm specific part and ferrite antenna |
| HW-006 | DCF77 GPIO assignment | ✅ Resolved — time-code GPIO 11 (input, pull-up), enable GPIO 12 (output); see §3, §7 |
| HW-007 | RTC selection and interface | ✅ Resolved — DS1307Z on I2C (SDA 8 / SCL 9, addr 0x68); 5 V part, I2C level-shifted to 3.3 V; 32.768 kHz crystal; CR2032 backup (see §8) |
| HW-008 | RTC backup battery life | ⚠ Open — confirm CR2032 lifetime at the DS1307 backup current and specify the holder / replacement access |
| HW-009 | Panel LED and encoder GPIOs | ✅ Resolved — LEDs GPIO 4–7; encoder A/B/button GPIO 13/14/47 (see §3, PMC-GUI-001) |
| HW-010 | Module carrier circuitry | ⚠ Open — the WEMOS LOLIN S3 dev board is no longer the target; the project PCB must provide the support circuitry the dev board supplied: 3.3 V regulation from USB 5 V, the USB-C connector and native-USB wiring, the debug UART (CH340 on UART0, or the module's native USB-Serial-JTAG — which would free GPIO 43/44), supply decoupling, and the antenna provisions. To be specified. |
| HW-011 | DCF77 / PWM coexistence (EMC) | ⚠ Open — the meter PWM and the DCF77 receiver share the enclosure. The PWM fundamental is set to **156.25 kHz** (raised from 80 kHz, which sat only 2.5 kHz from 77.5 kHz) so it and its harmonics stay clear of the DCF77 band (§5). Mitigations: keep the GPIO→R→C filter loop physically small, and site the ferrite antenna away from the PWM traces (§7.4). Confirm by measurement (HV-11) that DCF77 decodes with all three meters sweeping. |

---

## 13. Verification and Test Criteria (Hardware)

Electrical and mechanical checks supporting the functional acceptance criteria of PMC-FRS-001. Firmware-level test cases are in PMC-STD-001 §8.

| ID | Method / setup | Pass criterion | Verifies |
|----|---|---|---|
| HV-01 | Sweep each meter channel duty 0→232; measure V_out at the RC filter node | Output linear with duty (R² ≥ 0.999); ≈ 0 V at 0, ≈ 3.0 V at 232 | FR-DSP-004..006, DC-003..004 |
| HV-02 | At full-scale duty, check needle against the mechanical end-stop | Needle near full scale with margin to the end-stop | FR-DSP-005, FR-DSP-014 |
| HV-03 | Observe ripple at the meter terminals at a held duty | Ripple negligible (< ~1 % FSD); no visible needle jitter | FR-DSP-008, IC-HW-002 |
| HV-04 | Power-off / reset and observe the needles | Needles fall to zero promptly (no sustained drive) | NFR-PWR-001 |
| HV-05 | Check logic levels on the GNSS and DCF77 signal pins | All within 3.3 V logic; no level shifter required | IC-HW-003..006 |
| HV-06 | Verify GNSS antenna path and backup-power hot-start | Fix acquired via the antenna; hot-start after brief power loss | §6.5, §6.6 |
| HV-07 | Verify DCF77 reception with the ferrite antenna sited away from noise | Frames decode reliably at the installation site | FR-DCF-005..007, DC-007 |
| HV-08 | Measure total supply current in the worst case | Within the on-board 3.3 V regulator budget | §10 |
| HV-09 | Verify RTC I2C communication, timekeeping and battery-backup retention | RTC responds at 0x68; keeps time; retains time with main power removed (coin cell fitted) | FR-RTC-001..005, IC-HW-007 |
| HV-10 | Verify each status LED and the rotary encoder | All four LEDs controllable; encoder produces clean quadrature steps and debounced button events | IC-HW-008..009, PMC-GUI-001 |
| HV-11 | With DCF77 receiving, drive all three meters sweeping full scale; compare the DCF77 decode / parity-error rate against meters held static. Probe for PWM emission near 77.5 kHz at the ferrite antenna | No significant rise in DCF77 error rate with meters active; the 156.25 kHz PWM fundamental and its harmonics do not appear in the 77.5 kHz passband | FR-DCF-005..007, DC-004, HW-011 |

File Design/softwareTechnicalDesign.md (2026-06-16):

# Software Technical Design

## PanelMeterClock Firmware

---

## 1. Document Control

### 1.1 Identification

| Field | Value |
|---|---|
| Document title | Software Technical Design — PanelMeterClock Firmware |
| Document ID | PMC-STD-001 |
| Version | 0.3 (draft) |
| Date | 2026-06-15 |
| Author | Remko Welling |
| Status | Draft — under review |

### 1.2 Revision History

| Version | Date | Author | Change Summary |
|---|---|---|---|
| 0.1 | 2026-04-29 | Remko Welling | Initial draft; content migrated from PMC-FRS-001 appendices and supplemented with architecture design |
| 0.2 | 2026-06-09 | Remko Welling | Adopted the Greenhouse-Controller OTA design (new §5.13): dual app banks + paired dual-LittleFS assets, paired atomic commit (FW_DONE + 120 s fallback), 3-fail rollback with healthy-mark, `/api/ota` state machine, OTA-in-progress flag, reboot worker, `coredump` partition. Repartitioned §3.3; added `ota_task` (§4), NVS `system/*` keys (§6), OTA constants (§7), TC-OTA-001 (§8.14), DC-009/DC-010 (§9), IC-SW-004 (§10). Ed25519 firmware signing retained. |
| 0.3 | 2026-06-15 | Remko Welling | Raised meter PWM from 80 kHz to 156.25 kHz to clear the 77.5 kHz DCF77 band; reduced the RC filter capacitor 10 µF → 4.7 µF to match (PMC-HTD-001 §4.4, §5). Updated `PWM_FREQ_HZ` (§7), DC-004 (§9), §5.2; added a DCF77/PWM coexistence step to TC-DCF-001 (§8.7). |

### 1.3 Relationship to the FRS

This document is the companion technical design to **PMC-FRS-001 (Functional Requirements Specification)**. The FRS defines *what* the firmware shall do; this document defines *how* it is structured and implemented. Requirements are identified by their FRS identifiers (e.g., FR-DSP-006).

---

## 2. Target Platform

| Attribute | Value |
|---|---|
| Module | Espressif ESP32-S3-WROOM-1-N16R8 |
| CPU | Xtensa LX7 dual-core, 240 MHz |
| Flash | 16 MB quad SPI (N16) |
| RAM | 512 KB SRAM + 8 MB octal PSRAM (R8) |
| Framework | Espressif ESP-IDF 5.x (mandatory) |
| Build system | PlatformIO |
| RTOS | FreeRTOS (provided by ESP-IDF) |

---

## 3. Build System

### 3.1 `platformio.ini`

```ini
[env:esp32s3]
platform                = espressif32
board                   = esp32-s3-devkitc-1   ; ESP32-S3-WROOM-1 reference; adjust for the project PCB
framework               = espidf
monitor_speed           = 115200
board_build.flash_size  = 16MB
board_build.partitions  = partitions_ota.csv
; N16R8 octal PSRAM is enabled in sdkconfig (CONFIG_SPIRAM, CONFIG_SPIRAM_MODE_OCT).
; No external lib_deps: HTTP server (esp_http_server), WiFi (esp_wifi/esp_netif),
; mDNS (mdns), NVS (nvs_flash) and the UART/GPIO/I2C/LEDC drivers are ESP-IDF components.
```

### 3.2 Library Dependencies

| Library | Source | Purpose | Rationale |
|---|---|---|---|
| `esp_wifi` + `esp_netif` + `esp_event` | Built-in (ESP-IDF) | STA and AP mode (FR-NW-001..009) | Core ESP-IDF networking stack |
| `mdns` | Built-in (ESP-IDF component) | mDNS / DNS-SD registration (FR-NW-010..013) | No external dependency |
| `esp_http_server` | Built-in (ESP-IDF) | Embedded HTTP server and OTA upload (FR-WEB-001..053) | Streams the OTA body straight to `esp_ota_write()` |
| `nvs_flash` | Built-in (ESP-IDF) | NVS key-value storage (FR-DSP-010..012, FR-NW-001) | Native ESP-IDF NVS |
| Custom POSIX TZ parser | In-tree (`src/posix_tz.h`) | DST rule engine (FR-DST-001..006) | POSIX TZ strings are compact, updatable via NVS without firmware rebuild |
| GNSS NMEA parser | In-tree (`src/nmea.h`) | NMEA sentence parsing (FR-GPS-003) | Lightweight; parses $GPRMC/$GNRMC only |
| DCF77 time-code decoder | In-tree (`src/dcf77.h`) | DCF77 frame decode, validation and DST bits (FR-DCF-003..011) | Simple edge-timing decoder; no external library |
| RTC driver (DS1307) | In-tree (`src/ds1307.h`) | Battery-backed RTC over I2C (FR-RTC-001..006) | BCD register read/write at I2C 0x68 via the ESP-IDF I2C driver |
| ESP-IDF peripheral drivers (`driver/`) | Built-in (ESP-IDF) | UART (GNSS), GPIO (1PPS / DCF77 / encoder / LEDs), I2C (RTC), LEDC (PWM) | Native peripheral drivers |
| mbedTLS | Built-in (ESP-IDF) | Ed25519 (Ed25519ph + SHA-256) for FOTA signing (FR-SEC-001..005) | Enable `MBEDTLS_EDDSA_C` in `sdkconfig.defaults`; no extra flash cost |

### 3.3 Partition Table (`partitions_ota.csv`)

Dual app banks paired 1:1 with dual LittleFS asset partitions, plus `otadata` and a `coredump` partition (DC-005, §5.13):

```
# Name,   Type, SubType,  Offset,    Size,     Flags
nvs,      data, nvs,      0x9000,    0x5000,
otadata,  data, ota,      0xe000,    0x2000,
app0,     app,  ota_0,    0x10000,   0x200000,
app1,     app,  ota_1,    0x210000,  0x200000,
lfs0,     data, spiffs,   0x410000,  0x180000,
lfs1,     data, spiffs,   0x590000,  0x180000,
coredump, data, coredump, 0x710000,  0x10000,
```

- **`app0`/`app1`** — the two firmware banks (2 MB each); one active, one the OTA target.
- **`lfs0`/`lfs1`** — LittleFS web-asset partitions paired to the app banks (`app0→lfs0`, `app1→lfs1`); the running image mounts its own, the OTA writer writes the other (§5.13).
- **`coredump`** — crash-dump capture; must be erased on a new unit's first (greenfield) flash, not by OTA (DC-010).

The FOTA public key (FR-SEC-001) is embedded in the firmware binary at build time, not a partition.

---

## 4. FreeRTOS Task Architecture

All application work runs in FreeRTOS tasks created from `app_main()` (the ESP-IDF entry point).

| Task name | Core | Priority | Stack (bytes) | Responsibility |
|---|---|---|---|---|
| `display_task` | APP (1) | 10 | 4096 | Drives the three PWM meters; executes once per 1PPS tick event (FR-DSP-007) |
| `tick_task` | APP (1) | 9 | 2048 | Maintains UTC epoch; synthesises software 1PPS via FreeRTOS timer; arbitrates tick and epoch source; seeds from and writes back the RTC (FR-TIM-001..008, FR-RTC-001..006, FR-BOOT-016) |
| `ntp_task` | PRO (0) | 5 | 4096 | Issues NTP queries; disciplines the epoch (FR-NTP-001..004, FR-BOOT-006) |
| `wifi_task` | PRO (0) | 6 | 4096 | STA connect/reconnect with exponential back-off; AP fallback; mDNS start/stop (FR-NW-001..013) |
| `gnss_task` | PRO (0) | 7 | 4096 | UART read; NMEA parsing; 1PPS interrupt latch (FR-GPS-001..009); only created when GNSS is enabled |
| `dcf77_task` | PRO (0) | 7 | 3072 | DCF77 time-code edge capture, frame decode and validation, per-second tick (FR-DCF-001..012); only created when DCF77 is enabled |
| `http_task` | PRO (0) | 4 | 8192 | Embedded web server; serves the GUI pages and the `/api/ota/*` endpoints; owns the OTA state machine (FR-WEB-001..053, §5.13) |
| `ota_task` | PRO (0) | 5 | 4096 | Background OTA — extracts the buffered asset ZIP to the inactive LittleFS, performs the paired boot-slot commit, schedules the reboot worker (§5.13); only created during an update |
| `ui_task` | APP (1) | 8 | 2048 | Drives the four status LEDs and services the rotary encoder / time-set (PMC-GUI-001) |

**Inter-task communication:**

| Signal | Mechanism | Produced by | Consumed by |
|---|---|---|---|
| 1PPS tick event | `xTaskNotifyGive` | `tick_task` (software) or GNSS ISR (hardware) | `display_task` |
| UTC epoch update | Shared `volatile uint64_t` + `portENTER_CRITICAL` | `tick_task`, `ntp_task`, `gnss_task`, `dcf77_task` | All |
| Tick source selection | Atomic flag (`volatile uint8_t`) | `wifi_task`, `gnss_task`, `ntp_task`, `dcf77_task` | `tick_task` |
| Epoch source selection | Atomic flag (`volatile uint8_t`) | `gnss_task`, `ntp_task`, `dcf77_task` | `tick_task` |
| Config change | FreeRTOS event group | `http_task` | `wifi_task`, `ntp_task`, `gnss_task`, `dcf77_task` |
| OTA in progress | FreeRTOS event-group bit | `http_task`, `ota_task` | `wifi_task`, `tick_task`, status pushes (defer non-essential work, §5.13) |
| OTA state / progress | Mutex-guarded struct | `http_task`, `ota_task` | `http_task` (`GET /api/ota/status`) |

---

## 5. Module Design

### 5.1 Boot State Machine

The firmware progresses through three phases (FR-BOOT-001..017). The table below is the authoritative state-transition design.

| Current state | Event / guard | Next state | Actions on transition |
|---|---|---|---|
| *(start)* | Power-on | `PHASE_1` | Read the RTC and initialise the epoch from it (00:00:00 if the RTC time is invalid); start the 1 Hz software tick in `tick_task` (FR-RTC-002, FR-BOOT-002) |
| `PHASE_1` | Always (immediately) | `PHASE_2` | Create `wifi_task`; begin STA association attempt |
| `PHASE_2` | Always (if GNSS enabled) | `PHASE_3` | Create `gnss_task`; start GNSS UART; enable 1PPS GPIO interrupt |
| `PHASE_2` | Always (if DCF77 enabled) | `PHASE_3` | Create `dcf77_task`; power up receiver; enable time-code GPIO interrupt |
| `PHASE_2` | WiFi association success | `PHASE_2` (NTP attempt) | Issue NTP query from `ntp_task`; start mDNS; set DHCP hostname |
| `PHASE_2` | Valid NTP response | `STEADY` (NTP) | Set epoch from NTP; switch tick source to synthesised 1PPS; log sync event (NFR-MNT-002) |
| `PHASE_2` | WiFi or NTP failure | `PHASE_2` (retry) | Increment retry counter; log; wait 15 s then retry (FR-BOOT-008) |
| `PHASE_3` | GNSS fix valid | `STEADY` (GNSS override) | Override epoch from GNSS; switch tick source to hardware 1PPS; log (NFR-MNT-002) |
| `PHASE_3` | GNSS fix lost (> 5 s) | `PHASE_3` (degraded) | Fall back to NTP synthesised 1PPS; log (FR-BOOT-015) |
| `PHASE_3` | DCF77 valid AND no GNSS AND no NTP | `STEADY` (DCF77) | Set epoch from DCF77 (converted to UTC); drive tick from DCF77 second mark, else synthesised 1PPS; log (FR-BOOT-019) |
| `STEADY` (any) | NTP re-sync interval elapsed | `STEADY` | Issue NTP query; step epoch if error > 1 s, else slew (FR-TIM-006) |
| `STEADY` (any) | GNSS fix re-acquired | `STEADY` (GNSS override) | Re-enable hardware 1PPS; update epoch |
| `STEADY` (any) | Watchdog timeout | `PHASE_1` | Hardware reset; boot from scratch (NFR-REL-001..002) |

On every transition that sets the epoch from an accurate source — NTP, GNSS or DCF77, including the `STEADY` re-sync transitions above — `tick_task` also writes the corrected UTC back to the DS1307 RTC so the battery-backed time stays accurate (FR-RTC-003, §5.11).

### 5.2 Display and PWM Driver

**Duty cycle computation** (FR-DSP-006):

```
duty = zero_offset + round( value / range_max × (full_scale − zero_offset) )
```

Where:
- `value` — current time component (0–24 for hours, 0–60 for minutes/seconds)
- `range_max` — 24 (hours) or 60 (minutes/seconds)
- `zero_offset`, `full_scale` — per-meter calibration values from NVS (8-bit, 0–255)
- Result is clamped to [0, 255] before passing to `pwm_driver_set_duty()`

**PWM driver API** (NFR-PORT-001) — the sole interface between the display logic and LEDC hardware:

```cpp
// Research/PWMDriver/src/pwm_driver.h
void pwm_driver_init(pwm_driver_t *drv, int gpio, ledc_channel_t ch,
                     ledc_timer_t tmr, uint32_t freq_hz, uint8_t duty);
void pwm_driver_set_freq(pwm_driver_t *drv, uint32_t freq_hz);
void pwm_driver_set_duty(pwm_driver_t *drv, uint8_t duty);
```

`display_task` blocks on `ulTaskNotifyTake(pdTRUE, portMAX_DELAY)` and wakes on each 1PPS event. It applies the UTC-to-local conversion, computes duty for each meter, and calls `pwm_driver_set_duty()` three times. Total latency budget: < 10 ms (NFR-PERF-001).

**GPIO and LEDC assignments:**

| Meter | GPIO | LEDC channel | LEDC timer | Range |
|---|---|---|---|---|
| Hours | 15 | `LEDC_CHANNEL_0` | `LEDC_TIMER_0` | 0–24 |
| Minutes | 16 | `LEDC_CHANNEL_1` | `LEDC_TIMER_1` | 0–60 |
| Seconds | 17 | `LEDC_CHANNEL_2` | `LEDC_TIMER_2` | 0–60 |

PWM frequency: 156 250 Hz (80 MHz ÷ 512, exact); resolution: 8-bit; LEDC clock: 80 MHz (DC-004). The frequency clears the 77.5 kHz DCF77 band — see PMC-HTD-001 §5 and §7.4.  
Full-scale duty for 3.0 V output: 232 (= 232/255 × 3.3 V ≈ 3.0 V, FR-DSP-014, DC-003).

### 5.3 Timekeeping Engine

The internal clock is a 64-bit UTC epoch (`uint64_t utc_epoch_s`) plus a sub-second phase accumulator (`int32_t phase_us`).

**Software 1PPS synthesis:** A FreeRTOS timer fires at a nominal 1000 ms period. On each fire, `tick_task` adjusts the timer period by ±1 tick (±1 ms) based on accumulated NTP error, increments the epoch, and notifies `display_task`.

**Hardware 1PPS (GNSS):** A GPIO interrupt ISR calls `vTaskNotifyGiveFromISR` targeting `display_task` directly and increments the epoch from the ISR context via a critical section.

**Tick source arbitration** (FR-BOOT-016..017):

```
Tick mechanism (drives display_task):
  GNSS fix valid?          → hardware GNSS 1PPS ISR      (Priority 1)
  else DCF77 mark present?  → DCF77 per-second-mark ISR   (Priority 2)
  else                     → synthesised software 1PPS   (Priority 3)

Epoch source (sets utc_epoch_s — highest available wins):
  GNSS fix valid    → GNSS UTC                 (Priority 1)
  else NTP synced   → NTP-disciplined epoch    (Priority 2)
  else DCF77 valid  → DCF77 civil time → UTC   (Priority 3)
  else              → RTC (DS1307)             (Priority 4)
```

### 5.4 NTP Client

`ntp_task` sends a single NTPv4 UDP packet (RFC 5905) to the configured server (FR-NTP-001) and waits up to 5 s for a response. On success it computes the offset between the NTP timestamp and the local epoch and applies it:

- Error > 1 s: step (`utc_epoch_s` assigned directly)
- Error ≤ 1 s: slew (adjust FreeRTOS timer period over several seconds)

After the initial sync the task sleeps for `ntp_interval_s` (default 3600 s) before re-querying (FR-NTP-003).

### 5.5 WiFi Manager and mDNS

`wifi_task` owns the WiFi state machine using `esp_wifi` / `esp_netif` / `esp_event`. At startup it reads `wifi_ssid` and `wifi_pass` from NVS and brings up STA:

```c
esp_netif_set_hostname(sta_netif, mdns_hostname);   // DHCP Option 12 (FR-NW-013)
esp_wifi_set_config(WIFI_IF_STA, &sta_cfg);          // SSID / password
esp_wifi_start();
esp_wifi_connect();
```

**Reconnect back-off** (FR-NW-003): delay starts at 5 s, doubles on each failure, caps at 300 s.

**AP fallback** (FR-NW-005..009): if STA is not associated within `ap_timeout_s` seconds, activate the AP:

```c
// AP SSID = "PanelClock-AABB" (AABB = last 2 MAC bytes, uppercase hex)
esp_wifi_set_mode(WIFI_MODE_APSTA);
esp_wifi_set_config(WIFI_IF_AP, &ap_cfg);
```

**mDNS** (FR-NW-010..013): the `mdns` component is started on `IP_EVENT_STA_GOT_IP` and stopped on `WIFI_EVENT_STA_DISCONNECTED` (handled via `esp_event`). Not active during AP-only mode.

```c
// On IP_EVENT_STA_GOT_IP:
mdns_init();
mdns_hostname_set(mdns_hostname);                       // registers panelclock.local
mdns_service_add(NULL, "_http", "_tcp", 80, NULL, 0);  // DNS-SD advertisement

// On WIFI_EVENT_STA_DISCONNECTED:
mdns_free();
```

`mdns_hostname` defaults to `"panelclock"` (NVS key `clock/mdns_hostname`). It is the same value passed to `esp_netif_set_hostname()`.

### 5.6 GNSS Subsystem

**Module:** Quectel L76-M33 (GPS/GLONASS/Galileo/BeiDou, 3.3 V, NMEA 0183, 1PPS — see PMC-HTD-001 §6).

`gnss_task` is created only when `gnss_enabled` NVS flag is set (FR-GPS-001..002). It reads NMEA sentences from the GNSS UART, decodes `$GPRMC`/`$GNRMC`, and tracks fix validity. When a valid fix is obtained (FR-GPS-005), it writes the GNSS UTC time to `utc_epoch_s` and signals the tick source arbitrator to switch to hardware 1PPS.

**Hardware assignments (resolved):**

| Signal | GPIO | Direction | Notes |
|---|---|---|---|
| 1PPS input | **GPIO 10** | Input, no pull | Rising-edge interrupt; 3.3 V-tolerant |
| UART RX | **GPIO 18** | Input | UART1, ESP-IDF UART driver |
| UART TX | **GPIO 21** | Output | UART1; leave unconnected if no module config needed |

**UART initialisation:**

```c
uart_config_t cfg = { .baud_rate = gnss_baud, .data_bits = UART_DATA_8_BITS,
                      .parity = UART_PARITY_DISABLE, .stop_bits = UART_STOP_BITS_1 };
uart_param_config(UART_NUM_1, &cfg);
uart_set_pin(UART_NUM_1, GNSS_UART_TX_GPIO, GNSS_UART_RX_GPIO, -1, -1);
uart_driver_install(UART_NUM_1, 1024, 0, 0, NULL, 0);
```

`gnss_baud` is read from NVS key `clock/gnss_baud` (default 9600). Changing it via the web GUI GNSS page takes effect after `gnss_task` is restarted (no reboot required).

**1PPS interrupt:**

```c
gpio_config_t io = { .pin_bit_mask = 1ULL << GNSS_1PPS_GPIO,
                     .mode = GPIO_MODE_INPUT, .intr_type = GPIO_INTR_POSEDGE };
gpio_config(&io);
gpio_install_isr_service(0);
gpio_isr_handler_add(GNSS_1PPS_GPIO, gnss_pps_isr, NULL);
```

The ISR calls `vTaskNotifyGiveFromISR` to unblock `display_task` and increments `utc_epoch_s` inside a critical section. The interrupt is detached when `gnss_task` is stopped (GNSS disabled).

### 5.7 DST Engine

The DST engine is called once per network reconnection and every 24 hours (FR-DST-004). It selects a location source per the priority hierarchy (FRS Section 5.5) and resolves the applicable UTC offset using the **custom POSIX TZ string parser**.

**POSIX TZ string approach:** The timezone rule is stored in NVS key `clock/posix_tz` as a standard POSIX TZ string (e.g., `CET-1CEST,M3.5.0,M10.5.0/3` for Central European Time). The parser (`src/posix_tz.h`) computes the current UTC offset and DST state from this string and the UTC epoch, with no external dependencies. The string can be updated via the web GUI or populated automatically from the geolocation response, so timezone rules are updatable without a firmware rebuild.

**IP geolocation (Priority 2, resolved):**

Primary endpoint: `http://ip-api.com/json/?fields=timezone`  
Fallback endpoint: `http://worldtimeapi.org/api/ip`

The firmware tries the primary endpoint first with a 5-second timeout. On failure or non-200 response it falls back to worldtimeapi.org. The `timezone` field from either response (IANA name, e.g., `"Europe/Amsterdam"`) is used to look up the corresponding POSIX TZ string from a compact compile-time table embedded in the firmware. The resolved POSIX TZ string is then written to `clock/posix_tz` in NVS, making it available across reboots even if the internet is subsequently unreachable.

**DST source selection flowchart:**

```
GNSS enabled AND fix valid AND coordinates available?
  YES → use GNSS coordinates → resolve IANA timezone → look up POSIX TZ string → apply (Priority 1)
  NO  → internet reachable?
          YES → GET http://ip-api.com/json/?fields=timezone
                (fallback: http://worldtimeapi.org/api/ip)
                → resolve POSIX TZ string → write to NVS → apply (Priority 2)
          NO  → use posix_tz string already in NVS → apply (Priority 2b, cached)
                if NVS empty → no DST correction; apply UTC base offset only (Priority 3)
```

DST transitions are applied atomically by writing the new UTC offset to a `volatile int32_t utc_offset_s` guarded by a critical section (FR-DST-003).

### 5.8 HTTP Server and Web GUI

`http_task` runs the ESP-IDF **`esp_http_server`**. Static assets are served from the **active** LittleFS partition (§3.3, mounted through the VFS) by a wildcard `GET` URI handler; dynamic data (status page fields) is served via a lightweight JSON API polled by JavaScript (FR-WEB-034). Firmware and asset uploads are `POST` handlers under `/api/ota/*` that stream into the OTA subsystem (§5.13).

**Site map:**

```
/ (root — redirects to /status)
├── /status        Clock Status      (FR-WEB-030..035)
├── /calibrate     Meter Calibration (FR-WEB-010..015)
├── /wifi          WiFi Configuration(FR-WEB-020..024)
├── /gnss          GNSS Configuration(FR-WEB-025..027)
├── /dcf77         DCF77 Configuration(FR-WEB-050..053)
└── /update        Firmware Update   (FR-WEB-040..046)
```

All pages share a navigation bar with links to all six endpoints (FR-WEB-002..003).

**Firmware + asset update** is handled by the OTA subsystem over `POST /api/ota/firmware`, `POST /api/ota/assets` and `GET /api/ota/status` (the `/update` page is the browser front-end). Firmware and web assets are written to the inactive bank / inactive LittleFS and committed together; the full protocol, state machine, paired commit and rollback are specified in **§5.13**. The two-file detached **Ed25519** signature packaging (FR-SEC-001..006) is retained — rationale and alternatives in `Design/signatureConciderations.md`.

### 5.9 NVS Storage

All persistent configuration uses the ESP-IDF **NVS** library (`nvs_flash` / `nvs_open`), namespaces `"clock"` and `"meter"`. Keys, types, and defaults are listed in Section 6 below. NVS corruption is detected at startup from the `nvs_flash_init()` return code (`ESP_ERR_NVS_NO_FREE_PAGES` / `ESP_ERR_NVS_NEW_VERSION_FOUND`); on corruption the partition is erased and re-initialised to factory defaults (NFR-REL-003).

### 5.10 DCF77 Subsystem

**Receiver:** A longwave 77.5 kHz DCF77 receiver module with a ferrite-rod antenna and a demodulated, open-collector time-code output (see PMC-HTD-001 §7).

`dcf77_task` is created only when the `dcf77_enabled` NVS flag is set (FR-DCF-001..002). When DCF77 is disabled the receiver is held off via its enable line and the time-code interrupt is detached.

**Signal decoding:** The demodulated signal carries one amplitude-reduced mark per second (≈ 100 ms = binary 0, ≈ 200 ms = binary 1); the mark is omitted in second 59 to delimit the minute. An edge-triggered GPIO interrupt timestamps each edge; `dcf77_task` measures the active-pulse width to recover each bit and assembles the 59-bit minute frame. Bits 17–18 carry the CEST/CET announcement; the minute, hour and date fields are protected by even-parity bits.

**Hardware assignments (resolved):**

| Signal | GPIO | Direction | Notes |
|---|---|---|---|
| Time-code input | **GPIO 11** | Input, internal pull-up | Edge interrupt; polarity configurable (FR-DCF-004) |
| Receiver enable (PON) | **GPIO 12** | Output | Drives the module on/off; held off when DCF77 disabled |

**Validation and override:** A DCF77 time is accepted only after two consecutive, parity-valid, time-consistent minute frames (FR-DCF-007). The decoded CET/CEST time is converted to UTC using the time-zone bits Z1/Z2 (FR-DCF-009) and written to `utc_epoch_s` only while no valid GNSS fix and no NTP sync are present (FR-DCF-008). A subsequent GNSS fix or NTP sync overrides it. Loss of reception for longer than the configurable timeout (`DCF77_SIGNAL_LOST_TIMEOUT_S`, default 300 s) leaves the epoch running on the synthesised 1PPS (FR-DCF-010).

**DST change (FR-DCF-011):** Z1/Z2 give the current CET/CEST offset and the A1 bit announces a pending change one hour ahead, so the UTC derived from DCF77 stays continuous across a CET↔CEST transition. Display daylight saving remains governed by the DST engine (§5.7), independent of the DCF77 zone bits.

**Tick reference (FR-DCF-012):** the same edge interrupt that decodes the time-code also yields a once-per-second on-time mark. While GNSS 1PPS is absent and DCF77 marks are arriving, `tick_task` advances the 1-second tick from the DCF77 edge and phase-aligns the synthesised 1PPS to it; reception gaps fall back to the software 1PPS seamlessly.

**Polarity:** `dcf77_invert` (NVS) selects the active edge/level to match the receiver's output stage.

### 5.11 RTC (DS1307)

**Device:** Maxim **DS1307Z** I2C real-time clock (address `0x68`), 32.768 kHz crystal, coin-cell backup on VBAT (PMC-HTD-001 §8). The DS1307 operates at 5 V, so the I2C bus is level-shifted to the ESP32-S3's 3.3 V (PMC-HTD-001 §8).

The RTC is the persistent time-of-day store and the Priority-4 time source:

- **Boot:** `utc_epoch_s` is seeded from the RTC. The DS1307 clock-halt / oscillator-stopped flag is checked; if set (first use or lost backup power) the time is treated as invalid — the clock starts at 00:00:00 and the RTC indicator shows invalid (FR-RTC-005, PMC-GUI-001).
- **Discipline:** whenever GNSS, NTP or DCF77 yields accurate UTC, the corrected time is written back to the DS1307 (FR-RTC-003) so the retained time stays accurate across power cycles.
- **Fallback:** when no higher source is available, the displayed time is kept by the synthesised 1 Hz tick seeded from the RTC and is periodically re-aligned to it.
- **Manual set:** the rotary encoder writes the DS1307 directly (FR-RTC-004, PMC-GUI-001); the value is held on the backup battery.

All times in the DS1307 are stored as **UTC**, consistent with the internal epoch; conversion to local time for display is applied downstream (§5.7).

**Hardware assignment (resolved):** I2C `SDA` = GPIO 8, `SCL` = GPIO 9 (PMC-HTD-001 §3). The DS1307 `SQW/OUT` pin is unused in this design.

### 5.12 Panel Indicators and Control

Implements the physical operator interface specified in PMC-GUI-001; serviced by `ui_task`.

**Status LEDs (UI-IND):** four outputs drive the front-panel RTC/DCF/NTP/GNSS LEDs (GPIO 4–7, push-pull, series resistors). Each LED is off (source disabled/absent), blinking at `UI_BLINK_HZ` (≈ 1 Hz, acquiring) or steady (valid). The RTC LED is steady while the clock runs on the RTC and blinks ≈ 1 Hz when the RTC time is invalid; it blinks at `UI_SET_BLINK_HZ` (≈ 2 Hz) while set mode is active. The active source is the highest-priority lit LED (GNSS > NTP > DCF > RTC).

**Rotary encoder (UI-CTL):** quadrature channels on GPIO 13/14 and a push button on GPIO 47, all inputs with internal pull-ups and firmware debounce. A long press (`UI_LONGPRESS_MS`, 2 s) enters set mode at Hours; rotation adjusts the active field (wrapping); a short press advances Hours → Minutes → Seconds; a short press after Seconds writes the new time to the RTC (§5.11). Inactivity for `UI_SET_TIMEOUT_S` (30 s) exits without applying. While a field is edited the corresponding meter tracks the value. In normal mode the encoder has no effect (reserved).

Pin assignments are in PMC-HTD-001 §3; constants in §7.

### 5.13 OTA Update Subsystem

A network-only update path that flashes a new **firmware image and its matching web-asset bundle as one atomic unit**, survives power loss at any byte, and auto-rolls-back firmware that fails to boot. Adapted from the field-tested Greenhouse-Controller OTA design, with PMC's Ed25519 firmware signing retained. Cloud-pull, delta, resumable and concurrent updates are out of scope.

**Pillars**

- **Dual-bank firmware** (`app0`/`app1`, §3.3). Exactly one bank is active; the OTA writer targets the other. `otadata` records the boot bank and the bootloader swaps it atomically.
- **Coupled asset partitions** (`lfs0`/`lfs1`, §3.3), paired 1:1 with the app banks (`app0→lfs0`, `app1→lfs1`). The running image mounts its own LittleFS; the OTA writer writes the *other*. This prevents a refreshed browser landing on a UI built for a different firmware/API version.
- **Paired atomic commit.** The boot-slot swap happens only **after** the firmware is verified *and* the assets are extracted — there is never a state where new firmware runs against old assets.
- **Streaming firmware, buffered assets.** Firmware bytes stream to the inactive bank via `esp_ota_write()` (flat RAM cost); the asset ZIP is buffered whole in PSRAM (available on the N16R8), then extracted by `ota_task`.
- **Three-fail rollback** with a healthy-marking signal.

**HTTP protocol** (admin auth; `Content-Length` required on POSTs, else `400`):

| Method · Path | Body | Response |
|---|---|---|
| `POST /api/ota/firmware` | firmware `.bin` + detached Ed25519 signature | `200 {ok, awaiting_assets:true}` once written **and signature-verified** to the inactive bank (boot slot **not** yet swapped) |
| `POST /api/ota/assets` | STORE-only `.zip` (`application/zip`) | `202` — body buffered to PSRAM; extraction runs in `ota_task`; client polls status |
| `GET /api/ota/status` | — | `200 {ok, state, progress, error, bank, accepted}` |

`state ∈ { idle, fw_writing, fw_verifying, assets_buffering, assets_writing, fw_done, rebooting, error }`; `accepted` reflects the healthy/rollback flag.

**State machine** (mutex-guarded; the mutex is **not** held during flash erase/program, which can take seconds):

```
IDLE ──POST firmware──► FW_WRITING ──► FW_VERIFYING ──► FW_DONE ──120 s timeout──┐
  │                                                       │                      │
  │                                                  POST assets                 ▼
  └──POST assets──► ASSETS_BUFFERING ──► ASSETS_WRITING ──┴──────────────────► REBOOTING
   any state on error → ERROR (error string set);   ERROR / FW_DONE accept a fresh POST
```

- **Firmware path.** Stream to the inactive bank; `esp_ota_end()` validates the IDF SHA-256, then the **Ed25519 signature** is verified against the embedded public key (FR-SEC-001..006). The boot partition is **not** set here — the subsystem enters `FW_DONE` and waits up to `OTA_ASSET_FALLBACK_MS` (120 s) for an asset bundle, so a firmware-only push still commits.
- **Asset path.** `ota_task` parses the buffered ZIP — **STORE / method-0 only** (DC-009); a DEFLATE entry is rejected with a diagnostic — and extracts entries to the inactive LittleFS. If that partition fails to mount (fresh unit) it is **formatted first** (format-on-mount-failure). An **asset-only** session (no firmware uploaded this cycle) writes to the **active** LittleFS and does not swap the boot slot.
- **Paired commit.** Once the inactive LittleFS contents are durable, `ota_task` calls `esp_ota_set_boot_partition()` and schedules the reboot. A firmware rollback automatically points the image back at its own paired LittleFS, which already matches.
- **Three-fail rollback.** Every boot increments NVS `system/ota_fail_cnt`; after `OTA_HEALTHY_MS` (30 s) of healthy uptime `ota_mark_healthy()` resets it to 0. Reaching `OTA_FAIL_THRESHOLD` (3) before a healthy mark calls `esp_ota_mark_app_invalid_rollback_and_reboot()`, reverting to the previous bank. Deliberate restarts set NVS `system/ota_intentional` (paired with a "software reset" reason) so planned reboots are not counted.
- **Reboot scheduling.** The reset is performed by a small dedicated worker task (≈ 4 KB stack) spawned from the timer callback — never directly from the FreeRTOS timer-service task, whose stack the `esp_wifi_stop()` teardown would overflow.
- **OTA-in-progress flag.** An event-group bit (set on entering any active state, cleared on every exit including error) lets other tasks defer non-essential work (status pushes, reconnect timers) so the flash write is not slowed by bus contention.

Build-side artifacts — STORE-only ZIP construction, per-release archiving, asset-version stamping, and the operator push client — are tooling outside this document.

---

## 6. NVS Key Inventory

| Namespace | Key | Type | Default | Owning requirement |
|---|-----|---|---|---|
| `clock` | `wifi_ssid` | string | `""` | FR-NW-001 |
| `clock` | `wifi_pass` | string | `""` | FR-NW-001 |
| `clock` | `ap_timeout_s` | uint32 | `60` | FR-NW-005 |
| `clock` | `mdns_hostname` | string | `"panelclock"` | FR-NW-010 |
| `clock` | `ntp_server` | string | `"pool.ntp.org"` | FR-NTP-001 |
| `clock` | `ntp_interval_s` | uint32 | `3600` | FR-NTP-003 |
| `clock` | `gnss_enabled` | uint8 | `0` (disabled) | FR-GPS-001 |
| `clock` | `gnss_baud` | uint32 | `9600` | IC-HW-004 |
| `clock` | `gnss_lat_cache` | float | `0.0` | FR-GPS-009 |
| `clock` | `gnss_lon_cache` | float | `0.0` | FR-GPS-009 |
| `clock` | `dcf77_enabled` | uint8 | `0` (disabled) | FR-DCF-001 |
| `clock` | `dcf77_invert` | uint8 | `0` (non-inverted) | FR-DCF-004 |
| `clock` | `posix_tz` | string | `"CET-1CEST,M3.5.0,M10.5.0/3"` | FR-DST-001 |
| `meter` | `h_zero` | uint8 | `0` | FR-DSP-010 |
| `meter` | `h_full` | uint8 | `232` | FR-DSP-011, FR-DSP-014 |
| `meter` | `m_zero` | uint8 | `0` | FR-DSP-010 |
| `meter` | `m_full` | uint8 | `232` | FR-DSP-011, FR-DSP-014 |
| `meter` | `s_zero` | uint8 | `0` | FR-DSP-010 |
| `meter` | `s_full` | uint8 | `232` | FR-DSP-011, FR-DSP-014 |
| `system` | `ota_fail_cnt` | uint8 | `0` | §5.13 (3-fail rollback) |
| `system` | `ota_intentional` | uint8 | `0` | §5.13 (planned-reboot exempt) |
| `system` | `asset_version` | string | `""` | §5.13 (status; from asset manifest) |

All key names shall be defined as `constexpr char[]` constants in a single header (`nvs_keys.h`); no literal strings shall appear in application code (NFR-MNT-001).

---

## 7. Named Constants

All magic numbers shall be defined as named constants. The following table lists the most critical ones; the complete set lives in `config.h`.

| Constant | Value | Requirement |
|---|---|---|
| `PWM_FREQ_HZ` | 156250 | FR-DSP-008, DC-004 |
| `PWM_RESOLUTION_BITS` | 8 | DC-004 |
| `PWM_FULL_SCALE_DUTY` | 232 | FR-DSP-014, DC-003 |
| `METER_HOURS_GPIO` | 15 | IC-HW-001 |
| `METER_MINUTES_GPIO` | 16 | IC-HW-001 |
| `METER_SECONDS_GPIO` | 17 | IC-HW-001 |
| `NTP_DEFAULT_SERVER` | `"pool.ntp.org"` | FR-NTP-002 |
| `NTP_DEFAULT_INTERVAL_S` | 3600 | FR-NTP-003 |
| `WIFI_AP_TIMEOUT_DEFAULT_S` | 60 | FR-NW-005 |
| `MDNS_DEFAULT_HOSTNAME` | `"panelclock"` | FR-NW-010 |
| `WIFI_RECONNECT_MIN_S` | 5 | FR-NW-003 |
| `WIFI_RECONNECT_MAX_S` | 300 | FR-NW-003 |
| `NTP_RETRY_INTERVAL_S` | 15 | FR-BOOT-008 |
| `WATCHDOG_TIMEOUT_S` | 30 | NFR-REL-001 |
| `GNSS_FIX_LOST_TIMEOUT_S` | 5 | FR-GPS-007 |
| `GNSS_1PPS_GPIO` | 10 | IC-HW-003 |
| `GNSS_UART_RX_GPIO` | 18 | IC-HW-004 |
| `GNSS_UART_TX_GPIO` | 21 | IC-HW-004 |
| `GNSS_DEFAULT_BAUD` | 9600 | IC-HW-004 |
| `DCF77_SIGNAL_GPIO` | 11 | IC-HW-005 |
| `DCF77_PON_GPIO` | 12 | IC-HW-006 |
| `DCF77_ENABLED_DEFAULT` | 0 | FR-DCF-002 |
| `DCF77_SIGNAL_LOST_TIMEOUT_S` | 300 | FR-DCF-010 |
| `RTC_I2C_ADDR` | 0x68 | IC-HW-007, FR-RTC-001 |
| `I2C_SDA_GPIO` | 8 | IC-HW-007 |
| `I2C_SCL_GPIO` | 9 | IC-HW-007 |
| `LED_RTC_GPIO` | 4 | IC-HW-008, PMC-GUI-001 |
| `LED_DCF_GPIO` | 5 | IC-HW-008, PMC-GUI-001 |
| `LED_NTP_GPIO` | 6 | IC-HW-008, PMC-GUI-001 |
| `LED_GNSS_GPIO` | 7 | IC-HW-008, PMC-GUI-001 |
| `ENC_A_GPIO` | 13 | IC-HW-009, PMC-GUI-001 |
| `ENC_B_GPIO` | 14 | IC-HW-009, PMC-GUI-001 |
| `ENC_BTN_GPIO` | 47 | IC-HW-009, PMC-GUI-001 |
| `UI_LONGPRESS_MS` | 2000 | PMC-GUI-001 UI-CTL-002 |
| `UI_SET_TIMEOUT_S` | 30 | PMC-GUI-001 UI-CTL-007 |
| `UI_BLINK_HZ` | 1 | PMC-GUI-001 UI-IND |
| `UI_SET_BLINK_HZ` | 2 | PMC-GUI-001 UI-IND-008 |
| `DST_REFRESH_INTERVAL_S` | 86400 | FR-DST-004 |
| `GEOIP_PRIMARY_URL` | `"http://ip-api.com/json/?fields=timezone"` | FR-DST-004 |
| `GEOIP_FALLBACK_URL` | `"http://worldtimeapi.org/api/ip"` | FR-DST-004 |
| `GEOIP_TIMEOUT_MS` | 5000 | FR-DST-004 |
| `POSIX_TZ_DEFAULT` | `"CET-1CEST,M3.5.0,M10.5.0/3"` | FR-DST-001 |
| `OTA_HEALTHY_MS` | 30000 | §5.13 (healthy-mark delay) |
| `OTA_FAIL_THRESHOLD` | 3 | §5.13 (rollback trigger) |
| `OTA_ASSET_FALLBACK_MS` | 120000 | §5.13 (firmware-only commit) |
| `OTA_REBOOT_TASK_STACK` | 4096 | §5.13 (reboot worker) |

---

## 8. Verification and Test Criteria

This section defines the technical test methods and pass/fail criteria that verify the functional requirements of PMC-FRS-001. Each test case (TC-*) maps to the FRS traceability matrix; the FRS states the observable acceptance criterion, this section states the method, setup and measurable pass criterion. Hardware-level checks (electrical, mechanical) are in PMC-HTD-001 §13.

### 8.1 Display Subsystem — TC-DSP-001

| Step | Method / setup | Pass criterion | Verifies |
|---|---|---|---|
| 1 | Inject known local times (00:00, 06:00, 12:00, 18:00, 23:59:59) via the debug time command | Each needle matches the expected position within ±1 scale division (≈ ±1 LSB of the 8-bit duty) | FR-DSP-001..003 |
| 2 | Configure a non-zero UTC offset; read meters at a known UTC instant | Meters show local time, not UTC | FR-DSP-003a |
| 3 | Sweep each channel 0→max in 16 steps; measure V_out at the RC filter node | V_out linear vs. duty (R² ≥ 0.999); ≈0 V at zero, ≈3.0 V at full scale | FR-DSP-004..006 |
| 4 | Observe needles for 10 min against a 1PPS reference | Exactly one step per second; no visible flicker, glitch or overshoot | FR-DSP-007..009 |
| 5 | Set per-meter calibration, power-cycle, re-read; then apply defaults reset | Calibration persists across power cycle; defaults place full scale below the end-stop | FR-DSP-010..014 |

### 8.2 Boot and Time-Source Acquisition — TC-BOOT-001..004

| Step | Method / setup | Pass criterion | Verifies |
|---|---|---|---|
| 1 | Power on with no network / GNSS / DCF77 | Display lives at 00:00:00 within ~2 s and advances at 1 Hz | FR-BOOT-001..004 |
| 2 | Provide WiFi + NTP | Clock joins WiFi and corrects to NTP time; failures retried and shown on status | FR-BOOT-005..010 |
| 3 | Provide a GNSS fix | Time switches to GNSS; tick follows the GNSS pulse | FR-BOOT-011..013 |
| 4 | Remove the GNSS fix | Falls back to NTP/internal with no jump > 1 s | FR-BOOT-014..015 |
| 5 | Enable DCF77 with only DCF77 available, then restore NTP/GNSS | DCF77 sets time; NTP/GNSS override cleanly; source changes logged | FR-BOOT-018..021 |
| 6 | Force tick-source changes | Seconds never jump > 1 count; each change logged | FR-BOOT-016..017 |

### 8.3 Timekeeping — TC-TIM-001

| Step | Method / setup | Pass criterion | Verifies |
|---|---|---|---|
| 1 | Set a known UTC and a non-zero offset | Internal time is UTC; local display = UTC + offset/DST | FR-TIM-001..003 |
| 2 | Drive ticks from GNSS pulse, internal, then DCF77 mark | Seconds advance correctly on each; gaps bridged smoothly | FR-TIM-004..007 |
| 3 | Inject a large then a small error at re-sync | Large error stepped; small error corrected without a visible jump | FR-TIM-006 |
| 4 | Present GNSS, NTP, DCF77 together, then remove in priority order | Highest-priority source governs at each stage | FR-TIM-008 |

### 8.4 NTP Synchronisation — TC-NTP-001

| Step | Method / setup | Pass criterion | Verifies |
|---|---|---|---|
| 1 | Configure a custom server; then clear it | Syncs via the configured server, and via the default when unset | FR-NTP-001..002 |
| 2 | Wait past the re-sync interval | Re-syncs automatically on schedule | FR-NTP-003 |
| 3 | Open the status page | NTP server, last sync, quality and next sync shown | FR-NTP-004 |

### 8.5 GNSS — TC-GPS-001

| Step | Method / setup | Pass criterion | Verifies |
|---|---|---|---|
| 1 | Toggle GNSS off/on; reboot | Setting persists; no GNSS activity when off | FR-GPS-001..002 |
| 2 | Acquire a fix | Time, fix status and position obtained; pulse drives the tick | FR-GPS-003..004 |
| 3 | Valid fix alongside NTP; then lose the fix | GNSS governs; lost fix falls back automatically | FR-GPS-005..007 |
| 4 | Power-cycle after a fix | Last position retained as a hint; feeds DST | FR-GPS-008..009 |

### 8.6 Daylight Saving — TC-DST-001

| Step | Method / setup | Pass criterion | Verifies |
|---|---|---|---|
| 1 | Source location from GNSS, then IP geolocation, then DCF77 only (CET) | Timezone/DST resolved from the highest available source | FR-DST-001 |
| 2 | Cross a CET↔CEST change with the network down | Local display shifts one hour at the right moment, smoothly, offline | FR-DST-002..003, FR-DST-006 |
| 3 | Reconnect on the IP-geolocation source | Location refreshed on reconnect and daily | FR-DST-004 |
| 4 | Open the status page | DST state, offset and source shown | FR-DST-005 |

### 8.7 DCF77 — TC-DCF-001

| Step | Method / setup | Pass criterion | Verifies |
|---|---|---|---|
| 1 | Toggle off/on; reboot; test both polarities | Off by default; setting persists; decodes with either polarity | FR-DCF-001..004 |
| 2 | Feed a clean signal, then a corrupt one | Date/time + CET/CEST recovered; bad frames rejected; time used only after confirmation | FR-DCF-005..007 |
| 3 | DCF77 only, then add NTP/GNSS | DCF77 sets UTC (correct CET/CEST offset); NTP/GNSS override it | FR-DCF-008..009 |
| 4 | Interrupt reception; cross a CET↔CEST change | No display disturbance; UTC continuous across the change | FR-DCF-010..011 |
| 5 | Remove the GNSS pulse with DCF77 present | Seconds tick follows the DCF77 mark; gaps fall back smoothly | FR-DCF-012 |
| 6 | Decode DCF77 with all three meters sweeping full scale (worst-case PWM activity) | Frames still decode with no significant rise in parity errors vs. meters static — confirms the 156.25 kHz PWM does not jam 77.5 kHz reception (cross-ref HV-11) | FR-DCF-005..007, DC-004, HW-011 |

### 8.8 Network and Discovery — TC-NW-001..002

| Step | Method / setup | Pass criterion | Verifies |
|---|---|---|---|
| 1 | Provide valid credentials | Connects and gets an address automatically | FR-NW-001..002 |
| 2 | Drop and restore WiFi | Reconnects on its own | FR-NW-003 |
| 3 | Start with no joinable network | Open fallback AP appears after the timeout; full GUI works on it; closes on joining | FR-NW-005..009 |
| 4 | From a LAN client | Resolves as `panelclock.local`; web service discoverable; not advertised in AP-only mode | FR-NW-010..013 |

### 8.9 Web GUI — TC-WEB-001..006

| Step | Method / setup | Pass criterion | Verifies |
|---|---|---|---|
| 1 | Load the GUI offline in a stock browser | All pages load from the device; nav works; no internet needed | FR-WEB-001..005 |
| 2 | Use each config page (calibrate, WiFi, GNSS, DCF77) | Settings apply and persist; calibration live-preview works | FR-WEB-010..027, 050..053 |
| 3 | Open the status page | All status fields present and auto-refresh | FR-WEB-030..035 |
| 4 | Upload good and tampered firmware | Good installs and reboots; tampered rejected with a clear error, clock unchanged | FR-WEB-040..046 |

### 8.10 Security / FOTA — TC-SEC-001

| Step | Method / setup | Pass criterion | Verifies |
|---|---|---|---|
| 1 | Inspect device key handling | Only the public verification key is present; it survives updates | FR-SEC-001..003 |
| 2 | Upload validly signed, unsigned, and altered packages | Only the valid one is accepted; others rejected before any write, with a logged reason | FR-SEC-004..006 |
| 3 | Deliver a signed update carrying a new key | New key installs; later updates verified against it | FR-SEC-007 |

### 8.11 Non-Functional — TC-NFR-001

| Step | Method / setup | Pass criterion | Verifies |
|---|---|---|---|
| 1 | Measure tick-to-meter latency and page load | Meters update within ~10 ms; pages load in a few seconds; display unaffected by sync | NFR-PERF-001..003 |
| 2 | Hang the firmware; corrupt stored settings | Auto-resets within ~30 s and reboots; corrupt settings reset to defaults and logged | NFR-REL-001..003 |
| 3 | Power off / reset | Needles fall to zero promptly | NFR-PWR-001 |
| 4 | Review configurability, logging and structure | Settings change at runtime without reflash; key events logged; drive layer isolated | NFR-MNT-001..002, NFR-PORT-001 |

### 8.12 Real-Time Clock — TC-RTC-001

| Step | Method / setup | Pass criterion | Verifies |
|---|---|---|---|
| 1 | Set a time (sync or encoder), remove main power briefly, re-boot | Clock resumes the correct time of day from the RTC | FR-RTC-001..002, FR-RTC-004 |
| 2 | Sync via GNSS/NTP/DCF77, then cold-boot offline | Boot time matches the previously-synced time (RTC written back) | FR-RTC-003 |
| 3 | Remove the backup battery, then boot | Time invalid → starts at 00:00:00; RTC indicator shows invalid | FR-RTC-005 |
| 4 | Provide a higher source while on RTC time | Higher source overrides the RTC | FR-RTC-006 |

### 8.13 Panel Indicators and Control — TC-UI-001

| Step | Method / setup | Pass criterion | Verifies |
|---|---|---|---|
| 1 | Drive each source to off / acquiring / valid | Each LED shows off / ≈1 Hz blink / steady accordingly; active source readable by priority | UI-IND-001..009 |
| 2 | Remove the RTC backup battery and boot | RTC LED blinks (invalid) and the clock starts at 00:00:00 | UI-IND-006, FR-RTC-005 |
| 3 | Long-press, rotate each field, short-press through H/M/S, confirm | Set mode entered; meters track edits; time written to the RTC and retained | UI-CTL-002..006, FR-RTC-004 |
| 4 | Enter set mode and wait out the timeout | Returns to normal display with the time unchanged | UI-CTL-007 |

### 8.14 OTA Update — TC-OTA-001

| Step | Method / setup | Pass criterion | Verifies |
|---|---|---|---|
| 1 | `POST /api/ota/firmware` a validly-signed image, then `POST /api/ota/assets` a STORE-only ZIP | Firmware verified to the inactive bank, assets extracted to the inactive LittleFS, boot slot swapped only after both; device reboots into the new pair | §5.13 (paired commit) |
| 2 | Cut power partway through the firmware write, the asset write, and the commit (three runs) | After every cut the device boots the previous bank with its matching assets; no firmware/asset mismatch | §5.13 (power-safe, coupled assets) |
| 3 | `POST /api/ota/firmware` only; send no assets | After `OTA_ASSET_FALLBACK_MS` the firmware-only update commits and boots | §5.13 (120 s fallback) |
| 4 | Upload firmware that never reaches a healthy mark; let it boot repeatedly | After `OTA_FAIL_THRESHOLD` failed boots the device rolls back to the previous bank; a planned reboot (`ota_intentional`) is not counted | §5.13 (3-fail rollback) |
| 5 | `POST /api/ota/assets` a DEFLATE-compressed ZIP; separately POST an unsigned / altered firmware | DEFLATE rejected with a diagnostic; unsigned/altered firmware rejected before any boot-slot change | §5.13, DC-009, FR-SEC-004..006 |
| 6 | `POST /api/ota/assets` only (no firmware) on a running unit | Assets written to the **active** LittleFS; boot slot unchanged | §5.13 (asset-only) |

---

## 9. Design Constraints

These constraints (moved from PMC-FRS-001) bound the implementation. Hardware specifics are detailed in PMC-HTD-001.

| ID | Constraint |
|----|---|
| DC-001 | Target is the ESP32-S3-WROOM-1-N16R8 module (16 MB quad flash, 8 MB octal PSRAM) on the project PCB. The firmware shall be built on **Espressif ESP-IDF 5.x** (PlatformIO, `framework = espidf`) running on FreeRTOS. The Arduino framework, other application frameworks, bare-metal and alternative RTOSes are not permitted. |
| DC-002 | The ESP32-S3 has no analogue DAC; all meter drive is produced by PWM + RC filtering via the LEDC peripheral. |
| DC-003 | Each meter is modified so 3 V gives full-scale deflection; design point 0–3 V (duty 0–232); the 3.3 V GPIO maximum is not used as full scale (see PMC-HTD-001 §4.3). |
| DC-004 | PWM is 8-bit (0–255) at **156.25 kHz** from the 80 MHz LEDC clock (exact ÷2 integer divider) — 256 discrete positions, no fractional duty. The frequency is chosen so the PWM fundamental and its harmonics stay clear of the 77.5 kHz DCF77 band (PMC-HTD-001 §5, §7.4, HW-011). |
| DC-005 | The flash partition table must include two OTA application banks **and two paired LittleFS asset partitions, plus an `otadata` and a `coredump` partition** (§3.3, §5.13); it is a build-time configuration and cannot be changed by FOTA. |
| DC-006 | The FOTA public key is embedded in the firmware binary at build time, excluded from OTA writes, and not modifiable at runtime. |
| DC-007 | DCF77 reception is limited to Central Europe (≈ 2 000 km from Mainflingen) and depends on local signal strength; it is an optional, region-specific source the design shall not rely on. |
| DC-008 | The DS1307Z RTC operates at 5 V; its I2C bus is level-shifted to the 3.3 V logic of the ESP32-S3, and it requires a 32.768 kHz crystal and a coin-cell backup (PMC-HTD-001 §8). |
| DC-009 | The on-device OTA ZIP extractor accepts STORE (method 0) entries only; DEFLATE is rejected (§5.13). The release asset bundle must therefore be built STORE-only. |
| DC-010 | The `coredump` partition must be erased on a new unit's first (greenfield) flash; OTA cannot write or erase it (§3.3, §5.13). |

---

## 10. External Interfaces

Moved from PMC-FRS-001. Pin-level detail is in PMC-HTD-001 §3; protocol and peripheral detail is in the module designs (§5).

### 10.1 Hardware Interfaces

| ID | Interface |
|----|---|
| IC-HW-001 | Meter PWM outputs use the GPIO / LEDC channels and timers assigned in PMC-HTD-001 §3 and §5. |
| IC-HW-002 | Each PWM channel has a dedicated RC low-pass filter (cutoff ≈ 16 Hz; PMC-HTD-001 §4.4). |
| IC-HW-003 | GNSS 1PPS on GPIO 10 — input, no internal pull, rising-edge interrupt (PMC-HTD-001 §3). |
| IC-HW-004 | GNSS UART on UART1 (RX GPIO 18, TX GPIO 21), default 9 600 baud, configurable (PMC-HTD-001 §6). |
| IC-HW-005 | DCF77 time-code on GPIO 11 — interrupt-capable input with internal pull-up, polarity configurable (PMC-HTD-001 §7). |
| IC-HW-006 | DCF77 enable (PON) on GPIO 12 — push-pull output; receiver held off when DCF77 disabled (PMC-HTD-001 §7). |
| IC-HW-007 | DS1307Z RTC on I2C — SDA GPIO 8, SCL GPIO 9, address 0x68; 5 V part with the bus level-shifted to 3.3 V (PMC-HTD-001 §3, §8). |
| IC-HW-008 | Four front-panel status LEDs (RTC/DCF/NTP/GNSS) on GPIO 4–7 — push-pull outputs with series resistors (PMC-HTD-001 §3). |
| IC-HW-009 | Rotary encoder on GPIO 13 (A) / 14 (B) and push button on GPIO 47 — inputs with internal pull-ups, firmware debounced (PMC-HTD-001 §3). |

### 10.2 Software and Protocol Interfaces

| ID | Interface |
|----|---|
| IC-SW-001 | NTP per NTPv4 (RFC 5905), UDP port 123. |
| IC-SW-002 | GNSS via NMEA 0183; at minimum `$GPRMC` / `$GNRMC` are parsed. |
| IC-SW-003 | Web GUI over HTTP/1.1, TCP port 80; HTTPS is out of scope. |
| IC-SW-004 | FOTA updates firmware and web assets together over `POST /api/ota/firmware`, `POST /api/ota/assets` and `GET /api/ota/status`; dual-slot app banks + paired dual LittleFS; assets delivered as a STORE-only ZIP; firmware Ed25519-signed (§5.13). |
| IC-SW-005 | DCF77 decoded from the one-minute amplitude-modulated time-code frame (PTB DCF77 standard). |

### 10.3 Human Interfaces

| ID | Interface |
|----|---|
| IC-HMI-001 | Primary UI is the embedded web GUI (FR-WEB-*). |
| IC-HMI-002 | Secondary diagnostic interface: serial debug stream at 115 200 baud, 8-N-1, on UART0 / USB-CDC. |

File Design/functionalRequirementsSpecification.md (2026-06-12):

# Functional Requirements Specification
## PanelMeterClock Firmware

---

## 1. Document Control

### 1.1 Identification

| Field | Value |
|---|---|
| Document title | Functional Requirements Specification — PanelMeterClock Firmware |
| Document ID | PMC-FRS-001 |
| Version | 0.2 (draft) |
| Date | 2026-04-29 |
| Author | Remko Welling |
| Status | Draft — under review |

### 1.2 Revision History

| Version | Date | Author | Change Summary |
|---|---|---|---|
| 0.1 | 2026-04-29 | Remko Welling | Initial draft |
| 0.2 | 2026-06-08 | Remko Welling | Restructured as a pure functional specification: each requirement paired with an acceptance / verification criterion; technical implementation detail and the interface/design-constraint sections moved to the Technical Design (PMC-STD-001 / PMC-HTD-001). |

### 1.3 Approvals

| Role | Name | Signature | Date |
|---|---|---|---|
| Author | Remko Welling | | |
| Reviewer | | | |

### 1.4 Distribution

| Recipient | Role |
|---|---|
| Remko Welling | Author / firmware developer |

---

## 2. Introduction

### 2.1 Purpose

This document defines the functional and non-functional requirements for the PanelMeterClock, together with the acceptance criteria by which each is verified in testing. It is the authoritative statement of *what* the clock shall do; *how* it is implemented is specified in the Technical Design (PMC-STD-001 Software Technical Design, PMC-HTD-001 Hardware Technical Design).

### 2.2 Scope

**In scope:**
- Firmware running on the ESP32-S3 target
- Three-meter display subsystem (hours, minutes, seconds)
- Boot phase state machine and time-source management
- NTP synchronisation and WiFi connectivity
- GNSS receiver integration and 1PPS tick discipline
- DCF77 longwave radio time-code receiver integration (offline time source)
- Battery-backed real-time clock (RTC) for time retention across power loss and local setting
- Automatic Daylight Saving Time (DST) detection and transition
- Embedded web GUI (calibration, configuration, status, FOTA)
- Firmware Over The Air (FOTA) with asymmetric-key authentication

**Out of scope:**
- PCB schematic and layout
- Mechanical enclosure and panel meter face design
- NTP server infrastructure
- GNSS hardware procurement and wiring
- HTTPS (out of scope; the web GUI is HTTP/1.1 only)

### 2.3 Intended Audience

- Firmware developer(s)
- Hardware designer
- Test engineer
- Project owner

### 2.4 How to Read This Document

Sections 6 through 15 contain numbered requirements in the form `<Type>-<Domain>-<NNN>` (see Section 3 for the numbering scheme). Each requirement is atomic and is paired with an **Acceptance / Verification Criteria** entry that defines, in observable terms, how the requirement is confirmed in testing. The corresponding test methods and pass conditions are held in the Technical Design (PMC-STD-001 §8 and PMC-HTD-001). Technical implementation decisions — pin assignments, components, protocols, algorithms, libraries — are specified in the Technical Design, not here.

Section 5 provides a system-level overview with priority hierarchies. Appendix B contains a complete boot-phase state-transition table. Appendix F tracks all open issues and TBD items.

---

## 3. Definitions, Acronyms, and Abbreviations

| Term | Definition |
|---|---|
| 1PPS | One Pulse Per Second — a precise timing signal, typically from a GNSS receiver, used as a hardware tick source |
| AP mode | Access Point mode — the ESP32-S3 hosts its own WiFi network for client devices to connect to |
| CET / CEST | Central European Time (UTC+1) / Central European Summer Time (UTC+2) — the civil time broadcast by the DCF77 transmitter |
| DCF77 | The German longwave (77.5 kHz) time-signal service transmitted from Mainflingen and derived from PTB atomic clocks; carries the full date and time once per minute. Used here as an offline radio time source |
| DST | Daylight Saving Time — the seasonal clock adjustment applied in many jurisdictions |
| Duty cycle | The fraction of one PWM period during which the output signal is high, expressed as an 8-bit integer (0 = 0 %, 255 = 100 %) |
| FOTA | Firmware Over The Air — uploading and applying new firmware via the embedded web GUI without physical access |
| FreeRTOS | Real-time operating system layer provided by ESP-IDF for the ESP32 |
| FSD | Full-Scale Deflection — the maximum needle position on a panel meter, corresponding to the maximum rated input |
| GNSS | Global Navigation Satellite System (encompasses GPS, GLONASS, Galileo, BeiDou, etc.) |
| IP geolocation | Inferring geographic location (latitude / longitude / timezone) from a device's public IP address by querying an external web service |
| LEDC | LED Control peripheral on the ESP32-S3; used in this project as a general-purpose high-frequency PWM generator |
| NMEA 0183 | A standard ASCII sentence protocol for GNSS receivers (e.g., $GPRMC, $GNRMC) |
| NTP | Network Time Protocol (NTPv4, RFC 5905) — used to synchronise the device clock over the internet |
| NVS | Non-Volatile Storage — the ESP-IDF key-value store in flash memory that persists across power cycles |
| OTA | Over The Air — generic term for wireless firmware updates; used here specifically for FOTA |
| Phase 1 / 2 / 3 | Named phases of the boot sequence as defined in Section 6 |
| PWM | Pulse Width Modulation — a technique for generating an analogue voltage from a digital output by varying duty cycle |
| RC filter | Resistor-capacitor low-pass filter; converts a PWM signal to a quasi-DC voltage proportional to duty cycle |
| RTC | Real-Time Clock — the battery-backed DS1307Z chip that retains the time while main power is off; it provides the time at boot and as the lowest-priority source, and can be set manually (PMC-GUI-001). See §5.4 (Priority 4). |
| STA mode | Station mode — the ESP32-S3 connects to an existing WiFi access point |
| Stratum | NTP hierarchy level; stratum 1 = directly connected to a reference clock; higher stratum = further removed |
| UTC | Coordinated Universal Time — the global time standard to which local time offsets and DST are applied |

---

## 4. References

### 4.1 Hardware Datasheets

| Document | Location |
|---|---|
| ESP32-S3-WROOM-1 Datasheet | `Documentation/esp32-s3-wroom-1_wroom-1u_datasheet_en.pdf` |
| ESP32-S3 Technical Reference Manual | `Documentation/esp32-s3_technical_reference_manual_en.pdf` |
| Siemens 1604P Panel Meter (DC 10.00 GF024T005) | `Documentation/` — Siemens product documentation |
| Quectel L76-M33 GNSS Module | `Documentation/` — Quectel L76-M33 Hardware Design Guide and Product Specification |
| DCF77 Receiver Module | `Documentation/` — DCF77 longwave (77.5 kHz) receiver module; ferrite antenna, demodulated time-code output |

### 4.2 Software and Protocol Standards

| Document | Reference |
|---|---|
| Network Time Protocol v4 | IETF RFC 5905 |
| NMEA 0183 GNSS Sentence Standard | NMEA 0183 v4.11 |
| IANA Time Zone Database | https://www.iana.org/time-zones |
| DCF77 Time-Code Format | PTB (Physikalisch-Technische Bundesanstalt) DCF77 specification |
| ESP-IDF LEDC Peripheral Guide | Espressif ESP-IDF Programming Guide, LEDC chapter |
| ESP-IDF OTA Update Guide | Espressif ESP-IDF Programming Guide, OTA chapter |

### 4.3 Internal Project Documents

| Document | Path |
|---|---|
| Hardware Technical Design | `Design/hardwareTechnicalDesign.md` |
| Software Technical Design | `Design/softwareTechnicalDesign.md` |
| GUI / User Interface Specification | `Design/guiSpecification.md` |
| FOTA Signature Considerations | `Design/signatureConciderations.md` |
| PWM Driver Design and API | `Research/PWMDriver.md` |
| PWM + RC Filter Verification Plan | `Research/PWMTest.md` |
| Design Trade-off Notes | `Design/notes.md` |

---

## 5. System Overview

### 5.1 Product Description

PanelMeterClock is a wall clock that displays the current **local time** on three moving-coil panel meters — one each for hours, minutes and seconds. It acquires accurate time from GNSS, the internet (NTP) and the DCF77 radio signal, applies the local timezone and daylight saving automatically, and is configured through an embedded web GUI. A battery-backed real-time clock (RTC) keeps time across power loss and can be set locally with a rotary encoder (PMC-GUI-001). Hardware and firmware implementation are specified in the Technical Design (PMC-HTD-001 / PMC-STD-001).

| Meter | Displayed value | Scale |
|---|---|---|
| Hours | Hour of day | 0 – 24 |
| Minutes | Minute of hour | 0 – 60 |
| Seconds | Second of minute | 0 – 60 |
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

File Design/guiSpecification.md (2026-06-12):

# GUI / User Interface Specification
## PanelMeterClock

---

## 1. Document Control

### 1.1 Identification

| Field | Value |
|---|---|
| Document title | GUI / User Interface Specification — PanelMeterClock |
| Document ID | PMC-GUI-001 |
| Version | 0.1 (draft) |
| Date | 2026-06-08 |
| Author | Remko Welling |
| Status | Draft — under review |

### 1.2 Revision History

| Version | Date | Author | Change Summary |
|---|---|---|---|
| 0.1 | 2026-06-08 | Remko Welling | Initial draft — physical operator interface (front panel, status LEDs, rotary encoder, connectors) |

### 1.3 Relationship to Other Documents

| Document | Role |
|---|---|
| PMC-FRS-001 Functional Requirements Specification | Defines *what* the clock does; the embedded **web GUI** is specified there (§12) |
| PMC-STD-001 Software Technical Design | Firmware design; will own the LED-status and encoder/set-mode logic |
| PMC-HTD-001 Hardware Technical Design | Hardware design; will own the LED and encoder GPIO assignment and circuitry |
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

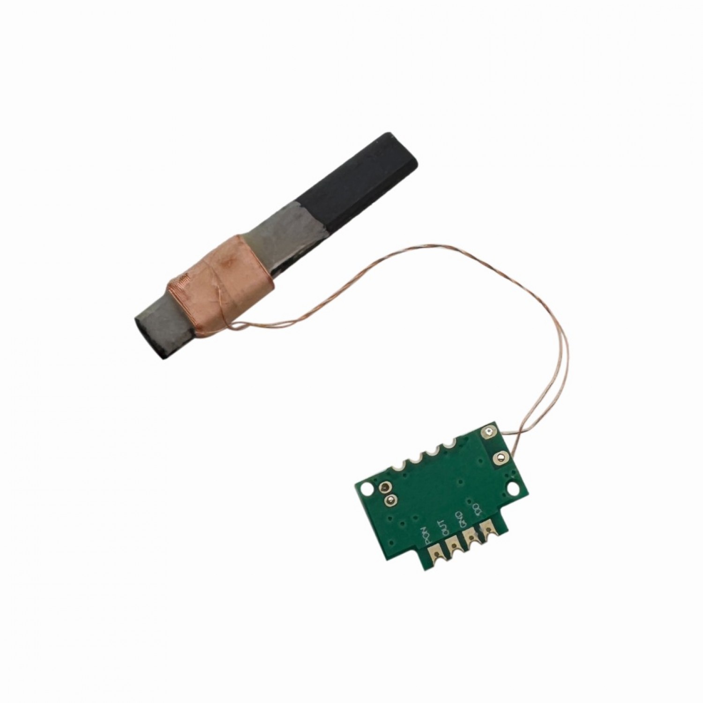
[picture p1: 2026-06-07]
Documentation/dcf77-radio-clock-receiver-BACK-1500x1500.jpg

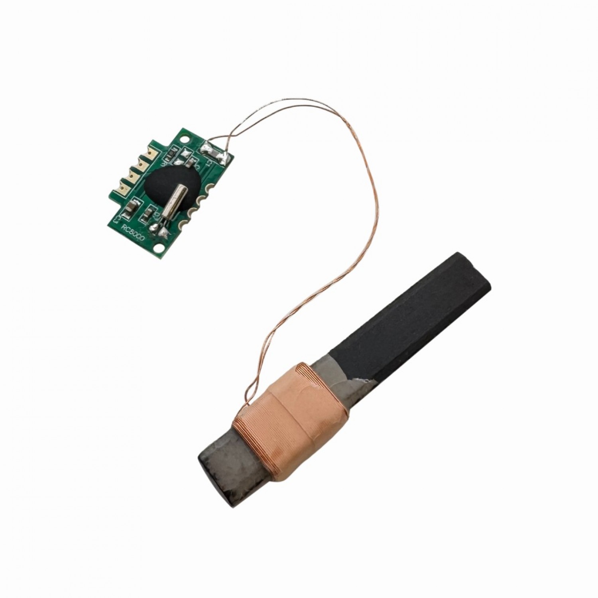
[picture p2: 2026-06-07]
Documentation/dcf77-radio-clock-receiver-1500x1500.jpg

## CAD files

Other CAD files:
Hardware/3DDesign/Siemens1604P_006.skp
Hardware/3DDesign/Siemens1604P_007.skp

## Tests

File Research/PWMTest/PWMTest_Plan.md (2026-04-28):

# PWMTest — PWM Panel Meter Verification

## Purpose

Verify whether PWM output from the ESP32-S3-WROOM-1, filtered through a single RC low-pass stage, produces a stable enough DC voltage to reliably deflect an analog panel meter. The ESP32-S3 has no built-in DAC, so PWM + RC filter is the primary candidate for driving the three meters in the final design.

Two potentiometers allow live adjustment of PWM frequency and duty cycle. Serial output reports current settings every second.

---

## Hardware

**MCU:** ESP32-S3-WROOM-1  
**Framework:** Arduino via PlatformIO (`esp32-s3-devkitc-1` board target)  
**Panel meter:** Siemens 1604P DC10.00GF024T005 (moving-coil, 10 V FSD)

---

## PWM Frequency Range: 20 kHz – 80 kHz

| Parameter | Value | Reason |
|---|---|---|
| Lower bound | 20 kHz | Just above human hearing — no audible whine |
| Upper bound | 80 kHz | Maximum practical with 8-bit resolution at 80 MHz LEDC clock |
| Resolution | 8-bit (0–255) | Sufficient for meter deflection across full range |
| Pot mapping | Linear: ADC 0–4095 → 20–80 kHz | Simple, predictable |

---

## RC Low-Pass Filter: R = 1 kΩ, C = 10 µF

| Parameter | Value |
|---|---|
| Cut-off frequency | fc = 1 / (2π × 1 kΩ × 10 µF) ≈ **15.9 Hz** |
| Attenuation at 20 kHz | ≈ −62 dB → residual ripple < 3 mV pk-pk |
| Panel meter bandwidth | ~1–3 Hz (mechanical) — well within filter rolloff |
| Component notes | Electrolytic or tantalum; observe polarity (+ toward GPIO15) |

---

## GPIO Pin Assignments

| Signal | GPIO | Notes |
|---|---|---|
| POT1 wiper (frequency) | **GPIO1** | ADC1_CH0 — safe, no WiFi conflict |
| POT2 wiper (duty cycle) | **GPIO2** | ADC1_CH1 |
| PWM output | **GPIO15** | LEDC channel 0 — not a strapping pin |
| Power | 3V3 pin | High side of both pots |
| Common | GND pin | Low side of both pots, C−, meter − |

Strapping pins (GPIO0, GPIO3, GPIO45, GPIO46) are avoided.

---

## Breadboard Wiring

```
ESP32-S3-WROOM-1
┌─────────────┐
│  3V3  ──────┼─── POT1 pin1 ───── POT2 pin1
│  GND  ──────┼─── POT1 pin3 ───── POT2 pin3
│  GPIO1 ─────┼─── POT1 wiper (pin2)
│  GPIO2 ─────┼─── POT2 wiper (pin2)
│  GPIO15 ────┼─── R (1 kΩ) ─┬─── Panel meter (+)
│             │               C (10 µF, + side toward GPIO15)
│             │               │
│  GND  ──────┼───────────────┴─── Panel meter (−)
└─────────────┘
```

**Connections summary (5 jumper wires + 2 passives + meter):**

| ESP32-S3 pin | Connects to |
|---|---|
| 3V3 | POT1 pin 1 and POT2 pin 1 (high side) |
| GND | POT1 pin 3, POT2 pin 3, C−, meter − |
| GPIO1 | POT1 wiper |
| GPIO2 | POT2 wiper |
| GPIO15 | R (1 kΩ) → node → meter (+) and C+ |

---

## Serial Output Format

Printed every 1 second at 115200 baud:

```
Freq: 40000 Hz | Duty: 128/255 ( 50.2%) | V_out ~1.65 V | ADC_f=2048 ADC_d=2050
```

---

## Verification Checklist

- [ ] Flash: `pio run -t upload`
- [ ] Open monitor: `pio device monitor`
- [ ] POT1 fully CCW → Freq ≈ 20 kHz; fully CW → Freq ≈ 80 kHz
- [ ] POT2 fully CCW → Duty 0%, meter at zero deflection
- [ ] POT2 fully CW → Duty 100%, meter at full-scale
- [ ] POT2 mid → meter settles near mid-scale (~1.65 V)
- [ ] Needle stable with no visible flutter at all pot positions
- [ ] No audible noise from meter coil or RC network

If flutter is observed: confirm C = 10 µF (not µH), check polarity, verify GND continuity.

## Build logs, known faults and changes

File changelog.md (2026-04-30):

# Changelog

All notable changes to this project are documented in this file.

The format is based on [Keep a Changelog](https://keepachangelog.com/), and this project adheres to [Semantic Versioning](https://semver.org/).

---

## [Unreleased] — 2026-04-30

### Added
- `Design/hardwareTechnicalDesign.md` §6.0 — Quectel L76-M33 module specification table (constellations, supply, baud rates, 1PPS, dimensions, TTFF, sensitivity)
- `Design/hardwareTechnicalDesign.md` §6.6 — VBAT backup power subsection: MS621FE coin cell or supercapacitor options for hot-start capability
- `Documentation/` — Quectel L76-M33 hardware design guide and product specification (three documents)

### Changed
- `Design/hardwareTechnicalDesign.md` §6.1 — signal overview table updated with L76-M33 pin names and VBAT row
- `Design/hardwareTechnicalDesign.md` §6.2 — level shifting confirmed not required for L76-M33 (3.3 V native)
- `Design/hardwareTechnicalDesign.md` §6.3 — UART section updated with PMTK baud-rate change command note
- `Design/hardwareTechnicalDesign.md` §6.4 — 1PPS pulse width referenced to L76-M33 spec (100 ms default)
- `Design/hardwareTechnicalDesign.md` §6.5 — antenna section updated: U.FL on-module connector, U.FL-to-SMA pigtail (W1) to chassis connector J1
- `Design/hardwareTechnicalDesign.md` §8 — power table updated with L76-M33 acquisition (18 mA) and tracking (15 mA) current; total system estimate added
- `Design/hardwareTechnicalDesign.md` §9 — U2 updated to Quectel L76-M33; BT1 (MS621FE backup cell) and W1 (U.FL-to-SMA pigtail) added
- `Design/hardwareTechnicalDesign.md` §10 — HW-001 closed (Quectel L76-M33 selected)
- `Design/functionalRequirementsSpecification.md` §4.1 — Quectel L76-M33 datasheet added to hardware references
- `Design/softwareTechnicalDesign.md` §5.6 — GNSS module identified as Quectel L76-M33
- `README.md` — hardware table updated with Quectel L76-M33 and antenna pigtail

### Changed
- `Design/hardwareTechnicalDesign.md` §4.3 — series resistor formula corrected to include R_filter (1 kΩ) in the DC series chain; measured values added (I_FSD = 1 mA, V_FSD = 82.2 mV, R_coil = 82.2 Ω); calculated R_series = 1917.8 Ω → specified as 2.0 kΩ E24
- `Design/hardwareTechnicalDesign.md` §9 — R4–R6 value updated to 2.0 kΩ ±1 % metal film
- `Design/hardwareTechnicalDesign.md` §10 — HW-002 closed (series resistor resolved by measurement); HW-003 dropped; HW-004 resolved as SMA female chassis connector
- `Design/hardwareTechnicalDesign.md` §6.5 — antenna subsection added: SMA female chassis-mount connector (J1)
- Repository root files rewritten to reflect PanelMeterClock project (previously contained Greenhouse Ventilation Controller content)

---

## [Unreleased] — 2026-04-29

### Added
- `Design/functionalRequirementsSpecification.md` — PMC-FRS-001 v0.1: full functional requirements specification covering boot phases, display subsystem, timekeeping, NTP, GNSS, DST, network/WiFi, web GUI, FOTA security, non-functional requirements, interface requirements, and design constraints
- `Design/softwareTechnicalDesign.md` — PMC-STD-001 v0.1: software technical design covering target platform, build system, FreeRTOS task architecture, module design (boot state machine, PWM driver, timekeeping, NTP client, WiFi/mDNS manager, GNSS, DST engine, HTTP server), NVS key inventory, named constants, and open technical issues
- `Design/hardwareTechnicalDesign.md` — PMC-HTD-001 v0.1: hardware technical design covering microcontroller module, GPIO pin assignment, panel meter drive circuit (series resistor modification, RC filter analysis, PWM-to-voltage mapping), LEDC configuration, GNSS interface, serial debug interface, power supply, component list, and open hardware issues
- `Design/signatureConciderations.md` — analysis of detached vs embedded FOTA signature schemes, verification process, four single-file alternatives, and comparison table

### Changed
- `Design/functionalRequirementsSpecification.md` — hardware detail and design appendices migrated to PMC-HTD-001 and PMC-STD-001:
  - §5.1 product description simplified; GPIO/LEDC table columns moved to HTD
  - §5.6 hardware constraints summary replaced with reference to HTD
  - IC-HW-001..004 simplified; component values and pin assignments reference HTD
  - DC-003 simplified; series resistor calculation detail moved to HTD §4.3
  - Appendices B, C, D, E replaced with references to STD sections
  - FR-DSP-006 duty formula replaced with behavioural description referencing STD §5.2
  - §4.3 references: HTD and STD added

### Added (network requirements)
- `Design/functionalRequirementsSpecification.md` §11.3 — mDNS requirements FR-NW-010..013: fixed hostname `panelclock` (resolves as `panelclock.local`), STA mode only, DNS-SD HTTP service advertisement (`_http._tcp`, port 80), DHCP client hostname (Option 12)
- `Design/functionalRequirementsSpecification.md` Appendix E — NVS key `clock/mdns_hostname` (default `"panelclock"`)
- `Design/functionalRequirementsSpecification.md` Appendix A — traceability row FR-NW-010..013 / TC-NW-002

### Resolved (open technical issues)
- TBD-001 — GNSS 1PPS GPIO: **GPIO 10**
- TBD-002 — GNSS UART: **UART1, GPIO 18 RX / GPIO 21 TX, 9600 baud (configurable via NVS)**
- TBD-005 — IP geolocation service: **ip-api.com (primary), worldtimeapi.org (fallback)**
- TBD-006 — Timezone library: **custom POSIX TZ string parser; rule stored in NVS key `clock/posix_tz`**
- TBD-007 — HTTP server library: **ESPAsyncWebServer + AsyncTCP**

---

## [0.1.0] — 2026-04-28

*Project initialised.*

### Added
- `Research/PWMDriver/` — PlatformIO project: production-quality PWM driver for three LEDC channels; FreeRTOS-aware (per-instance mutex, glitch-free duty updates via direct register writes)
- `Research/PWMTest/` — PlatformIO project: standalone 80 kHz PWM verification with potentiometer-controlled frequency and duty cycle
- `Research/PWMDriver.md` — PWM driver design rationale and API documentation
- `Research/PWMTest.md` — RC filter and PWM frequency verification plan
- `Hardware/Scale/` — panel meter scale face design files
- `Documentation/` — ESP32-S3-WROOM-1 datasheet, ESP32-S3 technical reference manual, LOLIN S3 schematic and dimensions
- `code_of_conduct.md`, `contributing.md` — community standards
- `LICENSE`, `license.md` — dual licence: source-available non-commercial (software) and CC BY-NC-ND 4.0 (hardware, documentation, images)

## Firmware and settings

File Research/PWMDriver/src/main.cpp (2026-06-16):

#include <Arduino.h>
#include "pwm_driver.h"

// Select exactly one mode (or neither for full pot control):
//   POT_CONTROL_DISABLED – fixed 156 kHz / fixed duty (FIXED_DUTY)
//   POT_DUTY_ONLY        – fixed 156 kHz / duty from pot
//   SWEEP_MODE           – fixed 156 kHz, duty sweeps 0→pot-max in 60 steps of 1 s each
#define POT_DUTY_ONLY
// #define POT_CONTROL_DISABLED
// #define SWEEP_MODE

const int   POT_FREQ_PIN        = 1;       // ADC1_CH0 - frequency control potentiometer
const int   POT_DUTY_PIN        = 2;       // ADC1_CH1 - duty cycle control potentiometer
const int   FREQ_MIN            = 20000;   // Hz
const int   FREQ_MAX            = 156000;  // Hz
const int   ADC_MIN             = 0;
const int   ADC_MAX             = 4095;    // 12-bit ADC
const int   ADC_RESOLUTION_BITS = 12;
const int   DUTY_MIN            = 0;
const int   DUTY_MAX            = 255;     // 8-bit duty cycle
const int   DUTY_INIT           = 128;     // 50% at startup
const int   FIXED_FREQ          = 156000;  // Hz - used when POT_CONTROL_DISABLED
const int   FIXED_DUTY          = 86;      // /255 - used when POT_CONTROL_DISABLED
const float SUPPLY_VOLTAGE_V    = 3.3f;
const int   SERIAL_BAUD_RATE    = 115200;
const int   PRINT_INTERVAL_MS   = 1000;
const int   CONTROL_INTERVAL_MS = 20;      // 50 Hz update rate
const int   SWEEP_STEPS         = 60;      // number of steps in SWEEP_MODE
const int   SWEEP_STEP_MS       = 1000;    // ms per step in SWEEP_MODE
const int   TASK_STACK_SIZE     = 4096;
const int   TASK_PRIORITY       = 5;
const int   NUM_PWM_CHANNELS    = 3;

// One independent driver instance per output channel.
// Each gets its own GPIO pin, LEDC channel, and LEDC timer.
static pwm_driver_t pwm[NUM_PWM_CHANNELS];

static const int            PWM_PINS[NUM_PWM_CHANNELS]     = { 15, 16, 17 };
static const ledc_channel_t PWM_CHANNELS[NUM_PWM_CHANNELS] = { LEDC_CHANNEL_0, LEDC_CHANNEL_1, LEDC_CHANNEL_2 };
static const ledc_timer_t   PWM_TIMERS[NUM_PWM_CHANNELS]   = { LEDC_TIMER_0,   LEDC_TIMER_1,   LEDC_TIMER_2   };

static void control_task(void *arg)
{
    unsigned long lastPrint = 0;
#ifdef SWEEP_MODE
    int sweepStep = 0;
#endif

    for (;;) {
#if defined(POT_CONTROL_DISABLED)
        int freq = FIXED_FREQ;
        int duty = FIXED_DUTY;
#elif defined(POT_DUTY_ONLY)
        int freq = FIXED_FREQ;
        int duty = map(analogRead(POT_DUTY_PIN), ADC_MIN, ADC_MAX, DUTY_MIN, DUTY_MAX);
#elif defined(SWEEP_MODE)
        int maxDuty = map(analogRead(POT_DUTY_PIN), ADC_MIN, ADC_MAX, DUTY_MIN, DUTY_MAX);
        int freq    = FIXED_FREQ;
        int duty    = map(sweepStep, 0, SWEEP_STEPS - 1, 0, maxDuty);
        sweepStep   = (sweepStep + 1) % SWEEP_STEPS;
#else
        int rawFreq = analogRead(POT_FREQ_PIN);
        int rawDuty = analogRead(POT_DUTY_PIN);

        int freq = map(rawFreq, ADC_MIN, ADC_MAX, FREQ_MIN, FREQ_MAX);
        int duty = map(rawDuty, ADC_MIN, ADC_MAX, DUTY_MIN, DUTY_MAX);
#endif

        for (int i = 0; i < NUM_PWM_CHANNELS; i++) {
            pwm_driver_set_freq(&pwm[i], (uint32_t)freq);
            pwm_driver_set_duty(&pwm[i], (uint8_t)duty);
        }

        unsigned long now = millis();
        if (now - lastPrint >= PRINT_INTERVAL_MS) {
            lastPrint = now;
            float dutyPct    = duty / (float)DUTY_MAX * 100.0f;
            float voltageOut = duty / (float)DUTY_MAX * SUPPLY_VOLTAGE_V;
#if defined(POT_CONTROL_DISABLED)
            Serial0.printf(
                "Freq: %5d Hz | Duty: %3d/255 (%5.1f%%) | V_out ~%.2f V"
                " | [fixed]\n",
                freq, duty, dutyPct, voltageOut);
#elif defined(POT_DUTY_ONLY)
            Serial0.printf(
                "Freq: %5d Hz | Duty: %3d/255 (%5.1f%%) | V_out ~%.2f V"
                " | [freq fixed, duty pot]\n",
                freq, duty, dutyPct, voltageOut);
#elif defined(SWEEP_MODE)
            Serial0.printf(
                "Freq: %5d Hz | Duty: %3d/255 (%5.1f%%) | V_out ~%.2f V"
                " | step=%2d/60 max=%3d\n",
                freq, duty, dutyPct, voltageOut, sweepStep, maxDuty);
#else
            Serial0.printf(
                "Freq: %5d Hz | Duty: %3d/255 (%5.1f%%) | V_out ~%.2f V"
                " | ADC_f=%4d ADC_d=%4d\n",
                freq, duty, dutyPct, voltageOut, rawFreq, rawDuty);
#endif
        }

#ifdef SWEEP_MODE
        vTaskDelay(pdMS_TO_TICKS(SWEEP_STEP_MS));
#else
        vTaskDelay(pdMS_TO_TICKS(CONTROL_INTERVAL_MS));
#endif
    }
}

void setup()
{
    Serial0.begin(SERIAL_BAUD_RATE);

#if defined(SWEEP_MODE) || defined(POT_DUTY_ONLY)
    analogReadResolution(ADC_RESOLUTION_BITS);
    analogSetPinAttenuation(POT_DUTY_PIN, ADC_11db);
#elif !defined(POT_CONTROL_DISABLED)
    analogReadResolution(ADC_RESOLUTION_BITS);
    analogSetPinAttenuation(POT_FREQ_PIN, ADC_11db);
    analogSetPinAttenuation(POT_DUTY_PIN, ADC_11db);
#endif

    for (int i = 0; i < NUM_PWM_CHANNELS; i++) {
        pwm_driver_init(&pwm[i], PWM_PINS[i], PWM_CHANNELS[i], PWM_TIMERS[i],
                        FIXED_FREQ, FIXED_DUTY);
    }

    Serial0.println("PWMDriver ready.");
    Serial0.println("GPIO1=freq pot | GPIO2=duty pot");
    Serial0.println("GPIO15=PWM ch0 | GPIO16=PWM ch1 | GPIO17=PWM ch2");
    Serial0.println("RC filter: R=1k, C=10uF, fc~16 Hz");
    Serial0.println("-----------------------------------------------------------");

    xTaskCreatePinnedToCore(
        control_task, "pwm_ctrl",
        TASK_STACK_SIZE, nullptr, TASK_PRIORITY,
        nullptr, APP_CPU_NUM);
}

void loop()
{
    vTaskDelay(portMAX_DELAY);  // all work is done in control_task
}

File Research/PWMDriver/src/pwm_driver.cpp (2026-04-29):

#include "pwm_driver.h"
#include "soc/ledc_reg.h"  // LEDC_LSCH0_* register addresses and bit masks

// ESP32-S3 LEDC low-speed channel registers have a uniform stride of 0x14
// between consecutive channels.  Channel N's registers sit at:
//   LEDC_LSCH0_<REG> + N * 0x14
// The DUTY_START (bit 31) and PARA_UP (bit 26) bit positions are identical
// across all low-speed channel CONF1/CONF0 registers.
static void ledc_write_duty(ledc_channel_t ch, uint8_t duty_8bit)
{
    uint32_t duty_reg  = LEDC_LSCH0_DUTY_REG  + ch * 0x14u;
    uint32_t conf1_reg = LEDC_LSCH0_CONF1_REG + ch * 0x14u;
    uint32_t conf0_reg = LEDC_LSCH0_CONF0_REG + ch * 0x14u;

    // 1. Write new duty to shadow register (Q4 format: 4 fractional bits)
    REG_WRITE(duty_reg,  (uint32_t)duty_8bit << 4);
    // 2. Arm output update at next cycle boundary (self-clearing bit)
    REG_WRITE(conf1_reg, LEDC_DUTY_START_LSCH0_M);
    // 3. PARA_UP: latch shadow → active registers (required for low-speed channels)
    REG_SET_BIT(conf0_reg, LEDC_PARA_UP_LSCH0_M);
}

static void timer_set_freq(ledc_timer_t timer, uint32_t freq_hz)
{
    const ledc_timer_config_t cfg = {
        .speed_mode      = LEDC_LOW_SPEED_MODE,
        .duty_resolution = LEDC_TIMER_8_BIT,
        .timer_num       = timer,
        .freq_hz         = freq_hz,
        .clk_cfg         = LEDC_AUTO_CLK,
    };
    ledc_timer_config(&cfg);
}

void pwm_driver_init(pwm_driver_t *drv, int gpio_pin,
                     ledc_channel_t channel, ledc_timer_t timer,
                     uint32_t freq_hz, uint8_t duty)
{
    drv->channel     = channel;
    drv->timer       = timer;
    drv->mutex       = xSemaphoreCreateMutex();
    drv->active_freq = freq_hz;

    timer_set_freq(timer, freq_hz);

    const ledc_channel_config_t cfg = {
        .gpio_num   = gpio_pin,
        .speed_mode = LEDC_LOW_SPEED_MODE,
        .channel    = channel,
        .intr_type  = LEDC_INTR_DISABLE,
        .timer_sel  = timer,
        .duty       = duty,
        .hpoint     = 0,
    };
    ledc_channel_config(&cfg);
    ledc_write_duty(channel, duty);
}

void pwm_driver_set_freq(pwm_driver_t *drv, uint32_t freq_hz)
{
    xSemaphoreTake(drv->mutex, portMAX_DELAY);
    if ((uint32_t)abs((int32_t)freq_hz - (int32_t)drv->active_freq) > 200u) {
        timer_set_freq(drv->timer, freq_hz);
        drv->active_freq = freq_hz;
    }
    xSemaphoreGive(drv->mutex);
}

void pwm_driver_set_duty(pwm_driver_t *drv, uint8_t duty_8bit)
{
    xSemaphoreTake(drv->mutex, portMAX_DELAY);
    ledc_write_duty(drv->channel, duty_8bit);
    xSemaphoreGive(drv->mutex);
}

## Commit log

2026-04-28 Add PWMTest PlatformIO project for PWM panel meter verification
2026-04-30 Updated general documentation and added 3D design of Panel meter
    [Siemens1604P_006.skp]
2026-06-07 docs(design): add DCF77 receiver as Priority-3 time source
    Document DCF77 longwave (77.5 kHz) time reception across the FRS, software
    and hardware design as a third time source, ranked GNSS > NTP > DCF77 >
    free-running internal clock.
    - Decode date + civil time and convert CET/CEST -> UTC via the Z1/Z2 zone
    bits; set the epoch only when GNSS and NTP are both absent
    (FR-DCF-005/008/009)
    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
    [Siemens1604P_006.skp, Siemens1604P_007.skp]
2026-06-12 feat(research): DCF77 PoC as ESP-IDF project with reusable dcf77 component
    Port the edge-timing decoder (PMC-STD-001 §5.10) from Arduino to native
    ESP-IDF 5.5: GPIO ISR service + driver/gpio, console on UART0, FreeRTOS
    tick at 1 kHz. Decoder packaged as components/dcf77 for direct reuse in
    the firmware; harness prints decode progress and confirmed time.
2026-06-12 chore(hardware): add KiCad library submodules and project gitignore
    Track espressif/kicad-libraries and pe1mew/my-KiCad-library as
    submodules of the panelMeterClock KiCad project, referenced by its
    fp-lib-table/sym-lib-table. Ignore KiCad-generated and user-local
    files (backups, autosaves, .kicad_prl, caches, netlists, fabrication
    outputs, VS Code .history).
2026-06-12 Added PCB design
    [panelMeterClock.kicad_pcb, panelMeterClock.kicad_sch]
2026-06-16 intermediate commit
    [panelMeterClock.kicad_sch]
